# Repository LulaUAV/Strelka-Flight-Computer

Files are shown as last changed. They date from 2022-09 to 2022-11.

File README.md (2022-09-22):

# Strelka-Flight-Computer
Strelka exists in the family of rocket dog flight computers. This flight computer is fully capable of deploying recovery events.

Strelka (Стрелка, "little arrow") was a dog that spent a day in space aboard Korabl-Sputnik 2 (Sputnik 5) on 19 August 1960 before safely returning to Earth.

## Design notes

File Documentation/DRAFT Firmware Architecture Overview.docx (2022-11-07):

# Firmware Architecture Overview

# Header Files:

actuator_control.h:

data_logging.h:

Ematch_actuators.h:

max_m10.h:

ms5611.h:

bmx055.h:

# Data handling:

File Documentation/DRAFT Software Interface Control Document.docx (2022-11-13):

# Software Interface Control Document

# Preface:

This document outlines the internal software interfaces within the Strelka PCB environment. These interfaces are separated into two sections being the communication between the host processor and power distribution processor and the communication between the host processor and the ground station over a 915MHz RF link.

# Actuator control interface:

This interface consists of a SPI communications bus between the host board and the power distribution board. Communications will be initiated by the master when the chip select (CS) pin is pulled low. The master either send commands or request data. Due to hardware limitations, SPI packets must be of a fixed length. The communication bus packets will consist of the following fields:

Packet field | Identifier | Payload | Padding | CRC32
Data type | uint8_t | uint8_t | uint8_t | uint32_t
Length (bytes) | 1 | variable | Variable | 4
Description | Signify the packet type | Fields containing fixed length payloads | Padding to ensure packet size is equal to PACKET_SIZE | 32-bit CRC checksum

## Packet types:

Set servo positions:

Sets the positions of the 4 servos.

Sent from master:

Length: 21 bytes

Set servo positions | Identifier | Servo 1 position | Servo 2 position | Servo 3 position | Servo 4 position | Padding | CRC32
Data type | uint8_t | uint32_t | uint32_t | uint32_t | uint32_t | uint8_t | uint32_t
Length (bytes) | 1 | 4 | 4 | 4 | 4 | 0 | 4
Value | 0x44 | - | - | - | - | 0 | -

Received from slave:

Set servo positions response | Identifier | Actuator control state TypeDef | CRC32
Data type | uint8_t | uint32_t | uint32_t
Length (bytes) | 1 | 1 | 4
Value | 0x44 | - | -

Set DC motor positions:

Sets the angular positions of the two DC motors.

Set DC motor positions | Identifier | Motor 1 position | Motor 2 position | CRC32
Data type | uint8_t | uint32_t | uint32_t | uint32_t
Length (bytes) | 1 | 4 | 4 | 4
Value | 0x45 | - | - | -

Set DC motor rate:

Sets the angular rate of the two DC motors.

Set DC motor rate | Identifier | Motor 1 position | Motor 2 position | CRC32
Data type | uint8_t | uint32_t | uint32_t | uint32_t
Length (bytes) | 1 | 4 | 4 | 4
Value | 0x46 | - | - | -

Set DC motor gains:

Sets the control gains used to control the DC motors.

Set DC motor gains | Identifier | Motor 1 Kp | Motor 1 Ki | Motor 1 Kd | Motor 2 Kp | Motor 2 Ki | Motor 2 Kd | CRC32
Data type | uint8_t | uint16_t | uint16_t | uint16_t | uint16_t | uint16_t | uint16_t | uint32_t
Length (bytes) | 1 | 2 | 2 | 2 | 2 | 2 | 2 | 4
Value | 0x47 | - | - | - | - | - | - | -

Request DC motor positions:

Sent from master:

Request stepper motor rate | Identifier | CRC32
Data type | uint8_t | uint32_t
Length (bytes) | 1 | 4
Value | 0x48 | -

Received from slave:

Request DC motor positions | Identifier | Motor 1 position | Motor 2 position | CRC32
Data type | uint8_t | uint32_t | uint32_t | uint32_t
Length (bytes) | 1 | 4 | 4 | 4
Value | 0x49 | - | - | -

Request DC motor rates:

Sent from master:

Request stepper motor rate | Identifier | CRC32
Data type | uint8_t | uint32_t
Length (bytes) | 1 | 4
Value | 0x4A | -

Received from slave:

Request DC motor positions | Identifier | Motor 1 rate | Motor 2 rate | CRC32
Data type | uint8_t | uint32_t | uint32_t | uint32_t
Length (bytes) | 1 | 4 | 4 | 4
Value | 0x4B | - | - | -

Set stepper motor position:

Sets the position of the single stepper motor.

Set stepper motor position | Identifier | Motor 1 position | CRC32
Data type | uint8_t | uint32_t | uint32_t
Length (bytes) | 1 | 4 | 4
Value | 0x4C | - | -

Set stepper motor rate:

Sets the angular rate of the stepper motor.

Set stepper motor rate | Identifier | Motor 1 position | CRC32
Data type | uint8_t | uint32_t | uint32_t
Length (bytes) | 1 | 4 | 4
Value | 0x4D | - | -

Request stepper motor rate:

Requests the angular rate of the stepper motor.

Sent from master:

Request stepper motor rate | Identifier | CRC32
Data type | uint8_t | uint32_t
Length (bytes) | 1 | 4
Value | 0x4E | -

Received from slave:

Set stepper motor rate | Identifier | Motor 1 position | CRC32
Data type | uint8_t | uint32_t | uint32_t
Length (bytes) | 1 | 4 | 4
Value | 0x4E | - | -

# Ground station control interface:

This interface consists of a RF link between the Strelka PCB (slave) and the ground station (master). The radio communication is at 915MHz using LoRa modulation. Communications are half duplex and always initiated by the ground station. Data will be transmitted back from the Strelka PCB only after a request is made by the ground station.

## Packet types:

Test gimbal:

Sent from master:

Test gimbal | Identifier | CRC32
Data type | uint8_t | uint32_t
Length (bytes) | 1 | 4
Value | 0x01 | -

Received from slave:

Test gimbal | Identifier | Result | CRC32
Data type | uint8_t | uint8_t | uint32_t
Length (bytes) | 1 | 1 | 4
Value | 0x01 | 0 or 1 | -

Get continuity:

Sent from master:

Get continuity | Identifier | CRC32
Data type | uint8_t | uint32_t
Length (bytes) | 1 | 4
Value | 0x02 | -

Received from slave:

Get continuity | Identifier | Main continuity | Drogue continuity | CRC32
Data type | uint8_t | uint8_t | uint8_t | uint32_t
Length (bytes) | 1 | 1 | 1 | 4
Value | 0x01 | 0 or 1 | 0 or 1 | -

Get battery voltage:

Sent from master:

Get battery voltage | Identifier | CRC32
Data type | uint8_t | uint32_t
Length (bytes) | 1 | 4
Value | 0x01 | -

Received from slave:

Get battery voltage | Identifier | Battery voltage | CRC32
Data type | uint8_t | uint32_t | uint32_t
Length (bytes) | 1 | 4 | 4
Value | 0x01 | 0 or 1 | -

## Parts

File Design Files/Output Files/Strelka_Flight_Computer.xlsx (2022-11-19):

Source: | C:\Users\thean\Documents\FYP\Strelka-Flight-Computer\Design Files\Strelka_Flight_Computer\Strelka_Flight_Computer.kicad_sch
Date: | 2022-11-12 10:20
Tool: | Eeschema (6.0.9)
Generator: | C:\Program Files\KiCad\6.0\bin\scripting\plugins/bom_csv_grouped_by_value.py
Component Count: | 166
Item | Qty | Reference(s) | Value | LibPart | Footprint | Datasheet | LCSC# | Link | Qty | Price (USD) | Price (AUD) | Total | Exchange rate (USB->AUD)
1 | 1 | AE1 | Antenna_Shield | Device:Antenna_Shield | Connector_Coaxial:SMA_Amphenol_132134_Vertical | ~ | C2874833 |  |  |  |  | $0.00 | 1.49
2 | 1 | AE2 | Antenna_Shield | Device:Antenna_Shield | Connector_Coaxial:U.FL_Hirose_U.FL-R-SMT-1_Vertical | ~ | C88373 |  | 10 | $0.16 | $0.23 | $2.31
3 | 1 | BT2 | MS621FE-FL11E | MS621FE-FL11E:MS621FE-FL11E | Footprints:BAT_MS621FE-FL11E | http://www.sii.co.jp/en/me/datasheets/ms-rechargeable/ms621fe/ |  | https://www.ebay.com.au/itm/263174584953 | 1 | $6.47 | $9.64 | $9.64
4 | 4 | C1, C4, 14, 16, C26, C27 | 2.2u | Device:C_Small | Capacitor_SMD:C_0603_1608Metric | ~ | C92760 |  |  |  | $0.00 | $0.00
5 | 2 | C2, C23, C47 | 1u | Device:C_Small | Capacitor_SMD:C_0603_1608Metric | ~ | C5673 |  |  |  | $0.00 | $0.00
6 | 1 | C3, C17, C18 | 10nF | Device:C_Small | Capacitor_SMD:C_0603_1608Metric | ~ | C342901 |  |  |  | $0.00 | $0.00
8 | 3 | C6, C7, C10, C12, C13, C28, C29, C30, C31, C36, C39, C48 | 100nF | Device:C_Small | Capacitor_SMD:C_0603_1608Metric_Pad1.08x0.95mm_HandSolder | ~ | C30926 |  |  |  | $0.00 | $0.00
9 | 4 | C8, C9, C11, C15, C40 | 10uF | Device:C_Small | Capacitor_SMD:C_0603_1608Metric_Pad1.08x0.95mm_HandSolder | ~ | C87152 |  |  |  | $0.00 | $0.00
13 | 2 | C19, C20 | 8pF | Device:C_Small | Capacitor_SMD:C_0603_1608Metric_Pad1.08x0.95mm_HandSolder | ~ | C575408 |  |  |  | $0.00 | $0.00
14 | 2 | C21, C22 | 18pF | Device:C_Small | Capacitor_SMD:C_0603_1608Metric_Pad1.08x0.95mm_HandSolder | ~ | C519452 |  |  |  | $0.00 | $0.00
18 | 1 | C37 | NC | Device:C_Small | Capacitor_SMD:C_0402_1005Metric | ~ |  |  |  |  | $0.00 | $0.00
19 | 1 | C38 | 4.7u | Device:C_Small | Capacitor_SMD:C_0603_1608Metric | ~ | C92758 |  | 50 | $0.01 | $0.02 | $1.11
21 | 1 | C41 | 1500u | Device:C_Polarized_Small | Capacitor_THT:C_Radial_D8.0mm_H11.5mm_P3.50mm | ~ | C248440 |  | 5 | $0.25 | $0.38 | $1.88
22 | 1 | C46 | 22u | Device:C_Small | Capacitor_SMD:C_0603_1608Metric | ~ | C2762594 |  | 5 | $0.08 | $0.12 | $0.62
24 | 7 | C49, C50, C52, C53, C54, C56, C57 | NC | Device:C_Small | Capacitor_SMD:C_0603_1608Metric | ~ |  |  |  |  | $0.00 | $0.00
25 | 1 | C51 | 820p | Device:C_Small | Capacitor_SMD:C_0603_1608Metric | ~ | C5186722 |  | 100 | $0.0028 | $0.004172 | $0.42
26 | 1 | C55 | 47uF | Device:C_Small | Capacitor_SMD:C_0805_2012Metric | ~ | C76636 |  | 5 | $0.27 | $0.41 | $2.04
27 | 3 | D1, D2, D4 | B5819W | Device:D_Schottky_Small | Diode_SMD:D_SOD-123 | ~ | C8598 |  | 20 | $0.03 | $0.05 | $0.95
28 | 1 | D3 | E6X0602QBAC1UDA | Device:LED | LED_SMD:LED_0603_1608Metric_Pad1.05x0.95mm_HandSolder | https://datasheet.lcsc.com/lcsc/2105241210_EKINGLUX-E6X0602QBAC1UDA_C375467.pdf | C375467 |  |  |  | $0.00 | $0.00
29 | 2 | D5, D9 | 1SS388 | Device:D_Schottky_Small_Filled | Diode_SMD:D_SOD-523 | https://datasheet.lcsc.com/lcsc/2204061830_TECH-PUBLIC-1SS388_C2987059.pdf | C2987059 |  | 20 | $0.03 | $0.04 | $0.89
30 | 1 | D6 | SP0504BAJT | Power_Protection:SP0504BAJT | Package_TO_SOT_SMD:SOT-353_SC-70-5 | http://www.littelfuse.com/~/media/files/littelfuse/technical%20resources/documents/data%20sheets/sp05xxba.pdf | C5116451 |  | 5 | $0.08 | $0.12 | $0.59
31 | 1 | D10 | ESD9B3.3ST5G | Diode:ESD9B3.3ST5G | Diode_SMD:D_0402_1005Metric | https://datasheet.lcsc.com/lcsc/2108131930_TECH-PUBLIC-TPESD0402G36V_C558621.pdf | C558621 |  | 40 | $0.03 | $0.05 | $1.90
32 | 1 | D11 | BAT54C | Diode:BAT54C | Package_TO_SOT_SMD:SOT-23 | http://www.diodes.com/_files/datasheets/ds11005.pdf | C37704 |  | 20 | $0.02 | $0.04 | $0.74
33 | 1 | D12 | RED_BLUE | Device:LED_Small | LED_SMD:LED_0603_1608Metric | ~ | C84263 |  | 50 | $0.01 | $0.01 | $0.63
34 | 1 | D13 | BZT52C3V6T | Device:D_Zener_Small_Filled | Diode_SMD:D_SOD-523 | https://datasheet.lcsc.com/lcsc/2108150230_MDD-Microdiode-Electronics--BZT52C3V6T_C2858499.pdf | C2858499 |  | 50 | $0.02 | $0.03 | $1.34
35 | 1 | D14 | DSK34 | Device:D_Schottky_Small_Filled | Diode_SMD:D_SOD-123 | https://datasheet.lcsc.com/lcsc/1912171423_High-Diode-SS34_C466502.pdf | C908230 |  | 20 | $0.03 | $0.05 | $0.95
36 | 2 | FB1, FB2 | BLM18PG221SN1D | Device:FerriteBead_Small | Inductor_SMD:L_0603_1608Metric | https://datasheet.lcsc.com/lcsc/1810311127_Murata-Electronics-BLM18PG221SN1D_C80165.pdf | C80165 |  | 50 | $0.01 | $0.02 | $0.89
37 | 1 | FB3 | HZ1005K182TFB03 | Device:FerriteBead_Small | Resistor_SMD:R_0402_1005Metric | ~ | C279553 |  | 50 | $0.01 | $0.02 | $0.85
39 | 2 | I1, I2 | AL5809-30S1-7 | Simulation_SPICE:IDC | Diode_SMD:D_SOD-123 | https://datasheet.lcsc.com/lcsc/1809290411_Diodes-Incorporated-AL5809-30S1-7_C151325.pdf | C151325 |  | 4 | $0.37 | $0.54 | $2.18
40 | 1 | IC1 | XTSD04GLGEAG | XTSD04GLGEAG:XTSD04GLGEAG | SON127P800X600X95-8N | https://datasheet.lcsc.com/szlcsc/2005251034_XTX-XTSD04GLGEAG_C558839.pdf | C558839 |  | 2 | $0.51 | $0.76 | $1.52
41 | 1 | IC2 | MAX-M10S-00B | MAX-M10S-00B:MAX-M10S-00B | Footprints:MAXM10S00B | https://content.u-blox.com/sites/default/files/MAX-M10S_IntegrationManual_UBX-20053088.pdf |  | https://www.digikey.com.au/en/products/detail/u-blox/MAX-M10S-00B/15712906 | 1 |  | $34.07 | $34.07
42 | 1 | J1 | 1S_LiPo_LARGE_HOLE_XT-30 | Connector:Conn_01x02_Female | Connector_AMASS:AMASS_XT30PW-M_1x02_P2.50mm_Horizontal | https://www.ebay.com.au/itm/274528359927 |  |  | 1 |  | $14.00 | $14.00
43 | 1 | J2 | SM04B-GHS-TB(LF)(SN)- | SM04B-GHS-TB_LF__SN_-:SM04B-GHS-TB(LF)(SN)- | Footprints:JST_SM04B-GHS-TB(LF)(SN)- | https://datasheet.lcsc.com/lcsc/1810261120_JST-Sales-America-SM04B-GHS-TB-LF-SN_C189895.pdf | C189895 |  | 10 | $0.13 | $0.19 | $1.91
44 | 1 | J3 | DB125-3.5-4P-GN-S | Connector:Screw_Terminal_01x04 | TerminalBlock_4Ucon:TerminalBlock_4Ucon_1x04_P3.50mm_Horizontal | https://datasheet.lcsc.com/lcsc/2106062245_DIBO-DB125-3-5-4P-GN-S_C2757925.pdf | C2757925 |  | 5 | $0.27 | $0.40 | $2.00
45 | 1 | J4 | SM06B-GHS-TB(LF)(SN) | SM06B-GHS-TB_LF__SN_:SM06B-GHS-TB(LF)(SN) | Footprints:JST_SM06B-GHS-TB(LF)(SN) |  | C133065 |  | 10 | $0.29 | $0.43 | $4.31
46 | 1 | J5 | USB_B_Micro | Connector:USB_B_Micro | Connector_USB:USB_Micro-B_Molex-105017-0001 | ~ |  |  |  |  | $0.00 | $0.00
47 | 1 | J6 | USB_B_Micro | :USB_B_Micro_1 | Connector_USB:USB_Micro-B_Molex-105017-0001 | ~ |  |  |  |  | $0.00 | $0.00
49 | 1 | L2 | 6u | Device:L_Small | Inductor_SMD:L_Bourns_SRP5030T | https://datasheet.lcsc.com/lcsc/2105092345_BOURNS-SRP5030T-6R8M_C1329837.pdf | C1329837 |  | 2 | $0.99 | $1.47 | $2.94
50 | 1 | MOSFET1 | DMG6968UDM-7 | DMG6968UDM-7:DMG6968UDM-7 | Footprints:DMG6968UDM-7 | https://www.diodes.com/assets/Datasheets/ds31758.pdf | C151635 |  | 2 | $0.21 | $0.31 | $0.63
51 | 2 | Q1, Q2 | CJK2333 | Transistor_FET:Si2319CDS | Package_TO_SOT_SMD:SOT-23 | https://datasheet.lcsc.com/lcsc/2010190933_Jiangsu-Changjing-Electronics-Technology-Co---Ltd--CJK2333_C504109.pdf | C504109 |  | 5 | $0.07 | $0.11 | $0.56
52 | 4 | Q3, Q4, Q8, Q9 | AO3401A | Transistor_FET:AO3401A | Package_TO_SOT_SMD:SOT-23 | http://www.aosmd.com/pdfs/datasheet/AO3401A.pdf | C347476 |  | 20 | $0.03 | $0.05 | $0.93
53 | 2 | Q5, Q10 | AP2300 | Transistor_FET:2N7002E | Package_TO_SOT_SMD:SOT-23 | https://datasheet.lcsc.com/lcsc/1912111437_ALLPOWER-ShenZhen-Quan-Li-Semiconductor-AP2300_C360338.pdf | C360338 |  |  |  | $0.00 | $0.00
54 | 2 | Q6, Q11 | MMBT2222 | Device:Q_NPN_BCE | Package_TO_SOT_SMD:SOT-23 | chrome-extension://efaidnbmnnnibpcajpcglclefindmkaj/https://www.onsemi.com/pdf/datasheet/mmbt2222lt1-d.pdf | C8512 |  |  |  | $0.00 | $0.00
55 | 10 | R3, R8, R29, R30, R32, R49, R50, R52, R64, R69 | 100k | Device:R_Small | Resistor_SMD:R_0603_1608Metric | ~ | C14675 |  | 100 | $0.0011 | $0.001639 | $0.16
56 | 1 | R7 | 330R | Device:R_Small | Resistor_SMD:R_0603_1608Metric | ~ | C105881 |  | 100 | $0.0013 | $0.001937 | $0.19
57 | 1 | R9 | 2.7k | Device:R_Small | Resistor_SMD:R_0603_1608Metric | ~ | C13167 |  | 100 | $0.0009 | $0.001341 | $0.13
58 | 2 | R10, R23 | 10k | Device:R_Small | Resistor_SMD:R_0603_1608Metric | ~ | C98220 |  |  |  | $0.00 | $0.00
59 | 2 | R11, R12, R21, R22, R25 | 10R | Device:R_Small | Resistor_SMD:R_0603_1608Metric | ~ | C109318 |  |  |  | $0.00 | $0.00
60 | 1 | R13 | 200R | Device:R_Small | Resistor_SMD:R_0603_1608Metric_Pad0.98x0.95mm_HandSolder | ~ | C114664 |  |  |  | $0.00 | $0.00
61 | 6 | R14, R15, R16, R17, R18, R19, R20, R40, R58, R55 | 0 | Device:R_Small | Resistor_SMD:R_0603_1608Metric_Pad0.98x0.95mm_HandSolder | ~ | C21189 |  | 100 | $0.001 | $0.00149 | $0.15
62 | 1 | R55 | 0 | Device:R_Small | Resistor_SMD:R_0402_1005Metric |  | C106231 |  | 100 | $0.0006 | $0.000894 | $0.09
64 | 1 | R24 | NC | Device:R_Small | Resistor_SMD:R_0603_1608Metric_Pad0.98x0.95mm_HandSolder | ~ |  |  |  |  | $0.00 | $0.00
65 | 2 | R27, R47 | 2R | Device:R_Small | Resistor_SMD:R_2512_6332Metric | https://lcsc.com/product-detail/Chip-span-style-background-color-ff0-Resistor-span-Surface-Mount_UNI-ROYAL-Uniroyal-Elec-HP122WF200KT4E_C91926.html | C91926 |  | 8 | $0.20 | $0.30 | $2.37
66 | 10 | R28, R31, R33, R34, R48, R51, R53, R54, R56, R57 | 1k | Device:R_Small | Resistor_SMD:R_0603_1608Metric | ~ | C22548 |  | 100 | $0.0011 | $0.001639 | $0.16
67 | 6 | R35, R36, R37, R38, R39, R60 | 47k | Device:R_Small | Resistor_SMD:R_0603_1608Metric | ~ | C105579 |  | 200 | $0.0013 | $0.001937 | $0.39
70 | 1 | R59 | 13k | Device:R_Small | Resistor_SMD:R_0603_1608Metric | ~ | C137796 |  | 100 | $0.0014 | $0.002086 | $0.21
71 | 1 | R61 | 56.2k | Device:R_Small | Resistor_SMD:R_0603_1608Metric | ~ | C2930117 |  | 100 | $0.0009 | $0.001341 | $0.13
72 | 1 | R62 | 82k | Device:R_Small | Resistor_SMD:R_0603_1608Metric | ~ | C23254 |  | 100 | $0.001 | $0.00149 | $0.15
73 | 1 | R63 | 27k | Device:R_Small | Resistor_SMD:R_0603_1608Metric | ~ | C22967 |  | 100 | $0.0009 | $0.001341 | $0.13
74 | 4 | R65, R66, R67, R68 | 33 | Device:R_Small | Resistor_SMD:R_0603_1608Metric_Pad0.98x0.95mm_HandSolder | ~ | C23140 |  | 100 | $0.0001 | $0.000149 | $0.01
75 | 2 | SW1, SW2 | SW_Push | Nebula-rescue:SW_Push-Switch-H7_FlightComputer-rescue | Button_Switch_SMD:SW_Push_SPST_NO_Alps_SKRK |  | C561518 |  | 20 | $0.05 | $0.08 | $1.60
76 | 1 | SW3 | SM02B-GHS-TB(LF)(SN) | Switch:SW_DIP_x01 | Footprints:SM02BGHSTBLFSN | https://datasheet.lcsc.com/lcsc/1810261111_JST-Sales-America-SM02B-GHS-TB-LF-SN_C189893.pdf | C189893 |  | 10 | $0.11 | $0.16 | $1.65
77 | 1 | U2 | AP9101CK6 | Battery_Management:AP9101CK6 | Package_TO_SOT_SMD:SOT-23-6 | https://www.diodes.com/assets/Datasheets/AP9101C.pdf | C151339 |  |  |  | $0.00 | $0.00
78 | 1 | U3 | AMS1117-3.3 | Regulator_Linear:AMS1117-3.3 | Package_TO_SOT_SMD:SOT-223-3_TabPin2 | http://www.advanced-monolithic.com/pdf/ds1117.pdf | C173386 |  |  |  | $0.00 | $0.00
79 | 1 | U4 | RFM95W-915S2 | RF_Module:RFM95W-915S2 | RF_Module:HOPERF_RFM9XW_SMD | https://www.hoperf.com/data/upload/portal/20181127/5bfcbea20e9ef.pdf | C2844473 |  |  |  | $0.00 | $0.00
80 | 1 | U5 | STM32F405RGTx | MCU_ST_STM32F4:STM32F405RGTx | Package_QFP:LQFP-64_10x10mm_P0.5mm | http://www.st.com/st-web-ui/static/active/en/resource/technical/document/datasheet/DM00037051.pdf | C15742 |  | 2 | $13.79 | $20.55 | $41.10
81 | 2 | U7, U8 | USBLC6-2SC6 | Power_Protection:USBLC6-2SC6 | Package_TO_SOT_SMD:SOT-23-6 | https://www.st.com/resource/en/datasheet/usblc6-2.pdf | C2687116 |  |  |  | $0.00 | $0.00
82 | 1 | U9 | CP2102N-Axx-xQFN28 | Interface_USB:CP2102N-Axx-xQFN28 | Package_DFN_QFN:QFN-28-1EP_5x5mm_P0.5mm_EP3.35x3.35mm | https://www.silabs.com/documents/public/data-sheets/cp2102n-datasheet.pdf | C1550553 |  | 1 | $1.12 | $1.67 | $1.67
83 | 2 | U10, U15 | LM321 | Amplifier_Operational:LM321 | Package_TO_SOT_SMD:SOT-23-5 | http://www.ti.com/lit/ds/symlink/lm321.pdf | C5189111 |  | 10 | $0.04 | $0.06 | $0.65
84 | 1 | U11 | BMX055 | BMX055:BMX055 | Footprints:BMX055 | https://datasheet.lcsc.com/lcsc/1811071031_Bosch-Sensortec-BMX055_C94022.pdf | C94022 |  | 2 | $15.82 | $23.57 | $47.14
85 | 1 | U12 | MS561101BA03-50 | MS561101BA03-50:MS561101BA03-50 | Footprints:MS561101BA03-50 | https://www.te.com/commerce/DocumentDelivery/DDEController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 |  |  | 1 |  | $20.93 | $20.93
86 | 1 | U16 | TPS61085DGKR | TPS61085DGKR:TPS61085DGKR | Footprints:SOP65P490X110-8N | https://www.ti.com/cn/lit/gpn/tps61085 | C113659 |  | 2 | $1.52 | $2.26 | $4.52
87 | 1 | Y1 | Q13FC1350000200 | Device:Crystal_Small | Crystal:Crystal_SMD_3215-2Pin_3.2x1.5mm | https://datasheet.lcsc.com/lcsc/1811081213_Seiko-Epson-Q13FC1350000200_C48615.pdf | C48615 |  |  |  | $0.00 | $0.00
88 | 1 | Y2 | X322524MOB4SI | Device:Crystal_GND24_Small | Crystal:Crystal_SMD_3225-4Pin_3.2x2.5mm | https://datasheet.lcsc.com/lcsc/2103291204_Yangxing-Tech-X322524MOB4SI_C70590.pdf | C70590 |  |  |  | $0.00 | $0.00
 |  |  |  |  |  |  |  |  |  | Total (AUD) |  | $216.36
 |  |  |  |  |  |  |  |  |  | Already purchased
 |  |  |  |  |  |  |  |  |  | Purchased

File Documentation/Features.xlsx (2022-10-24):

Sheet: Features
Feature | Notes | Product
USB
Boost converter | 1s lipo | FP6276BXR-G1 (https://www.lcsc.com/product-detail/DC-DC-Converters_Feeling-Tech-FP6276BXR-G1_C82652.html)
LVCO
Servo outputs
Radio | RFM95W
GPS
Continuity testing
Brownout protection
Buzzer
Status LEDs

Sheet: Continuity Testing
Parts required | Part number | Specs
Constant current source | LM334Z/NOPB | 1uA-10mA output, High side config
Op amp | LM324

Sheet: MCU Selection
MCU | CPU (MHz) | Flash (kB) | RAM (kB) | Extras | Price (USD)
STM32F402RCT6 (https://lcsc.com/product-detail/Microcontroller-Units-MCUs-MPUs-SOCs_STMicroelectronics-STM32F402RCT6_C2915304.html) | 84 | 256 | 64 | FPU | 5.4587
STM32F405RGT6 (https://lcsc.com/product-detail/ST-Microelectronics_STMicroelectronics-STM32F405RGT6_C15742.html) | 168 | 1000 | 192 | FPU | 15 | These are hot swappable if vcap_1 and vcap_2 for f405 can have capacitor replaced with 0 ohm resistor when F446
STM32F446RET6 (https://lcsc.com/product-detail/ST-Microelectronics_STMicroelectronics-STM32F446RET6_C69336.html) | 180 | 512 | 128 | FPU | 14.154
STM32WB55CGU6 (https://lcsc.com/product-detail/Microcontroller-Units-MCUs-MPUs-SOCs_STMicroelectronics-STM32WB55CGU6_C404023.html) | 64 | 1999 | 256 | BT | 10.61

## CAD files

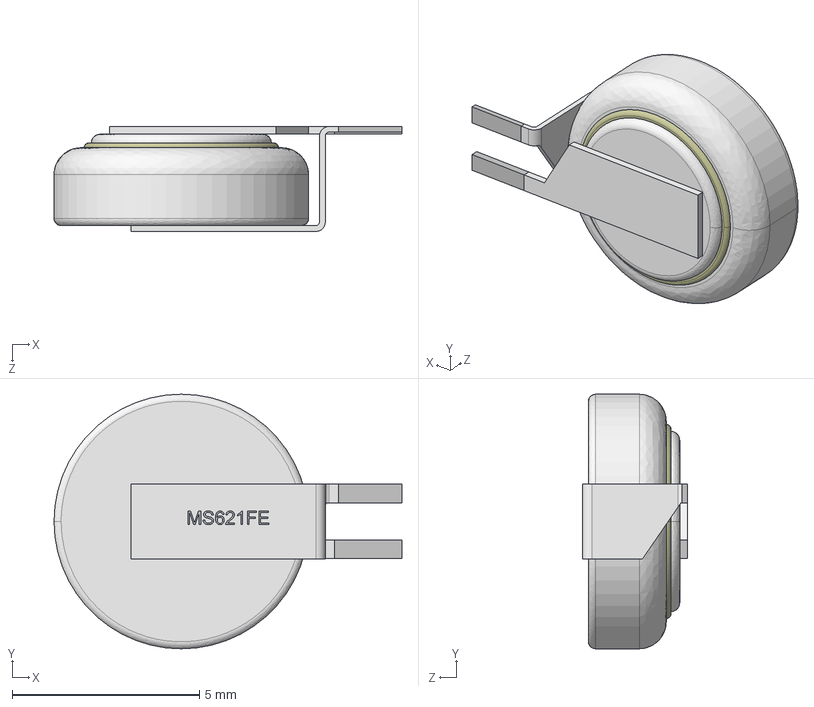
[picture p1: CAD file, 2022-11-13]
Local Library/3D Models/MS621FE-1.STEP
9.29 x 6.80 x 2.80 mm

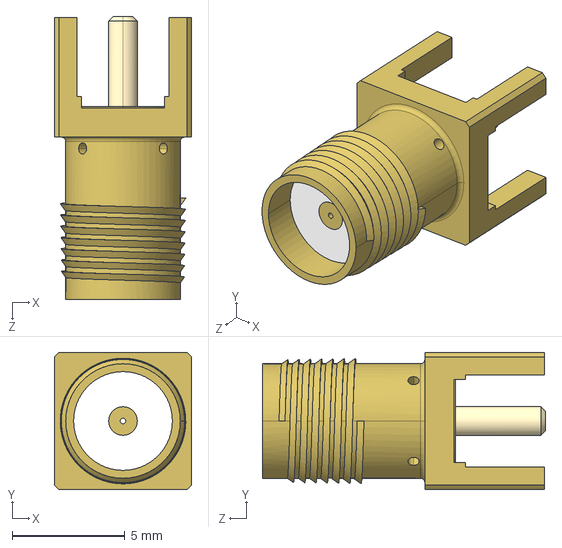
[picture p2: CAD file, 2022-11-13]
Local Library/3D Models/Molex - 73391-0060.STEP
6.08 x 6.08 x 12.6 mm

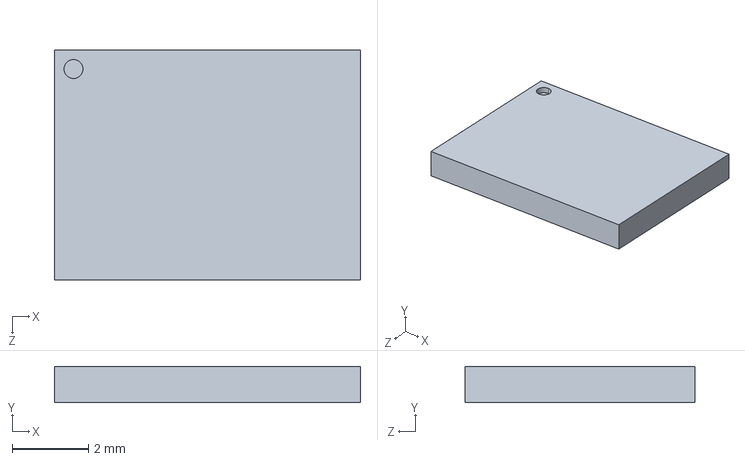
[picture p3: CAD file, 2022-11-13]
Local Library/3D Models/XTSD04GLGEAG.STEP
8.05 x 0.95 x 6.05 mm

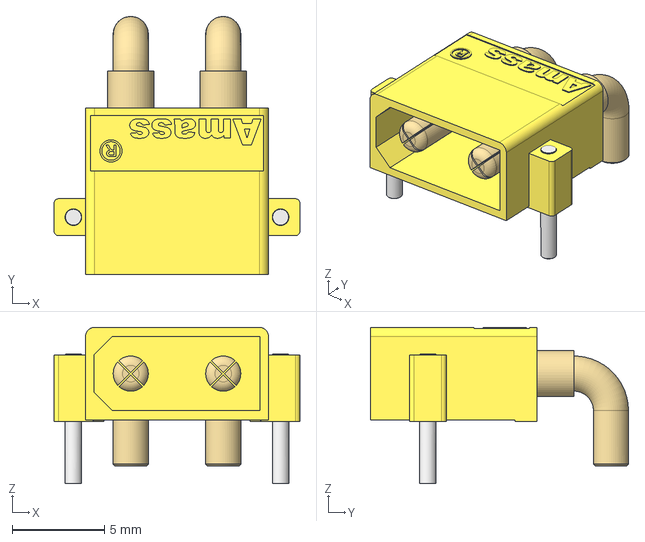
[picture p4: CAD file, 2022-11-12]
Local Library/3D Models/Amass_XT30PW-M.stp
13.3 x 13.9 x 8.45 mm

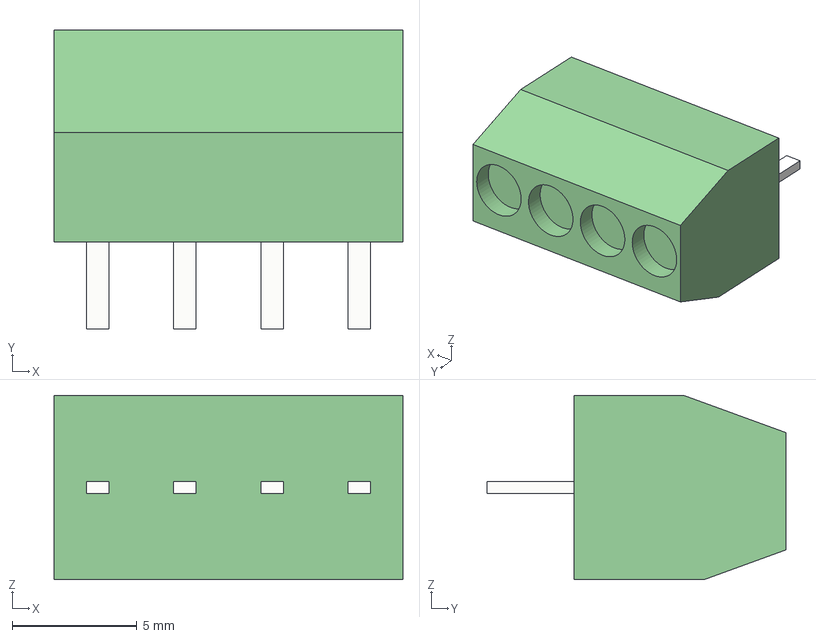
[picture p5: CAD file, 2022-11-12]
Local Library/3D Models/DB125-3.5-4P-GN-S.step
14.0 x 12.0 x 7.40 mm

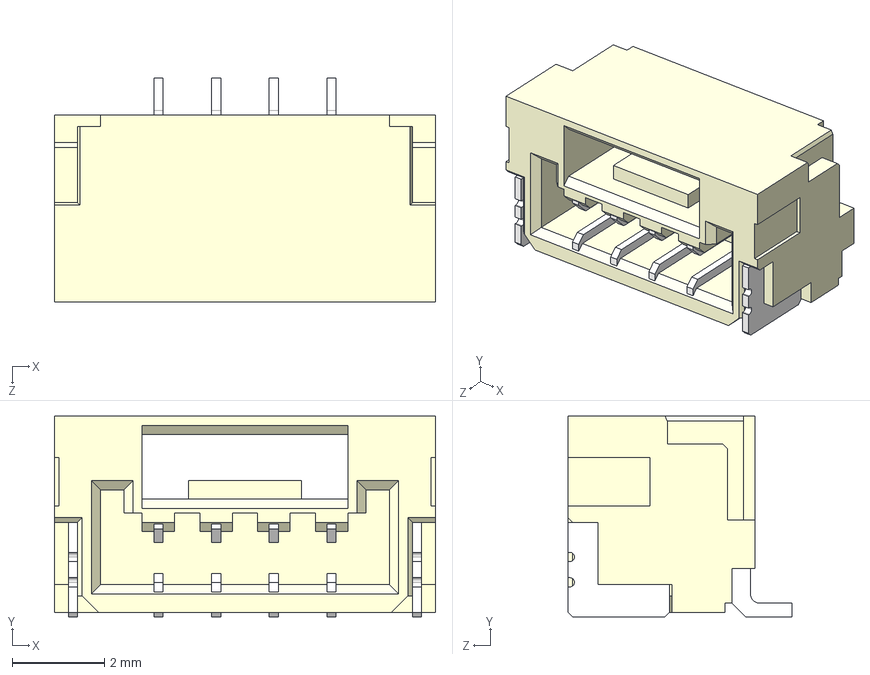
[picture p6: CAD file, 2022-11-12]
Local Library/3D Models/SM04B-GHS-TB_LF__SN_-.step
8.25 x 4.35 x 4.85 mm

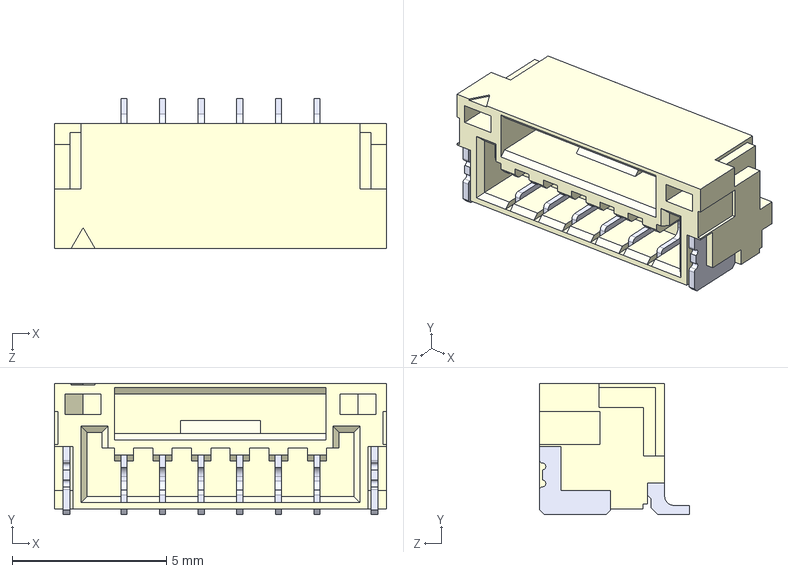
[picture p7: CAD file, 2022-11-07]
Local Library/3D Models/SM06B-GHS-TB_LF__SN_.step
10.8 x 4.25 x 4.85 mm

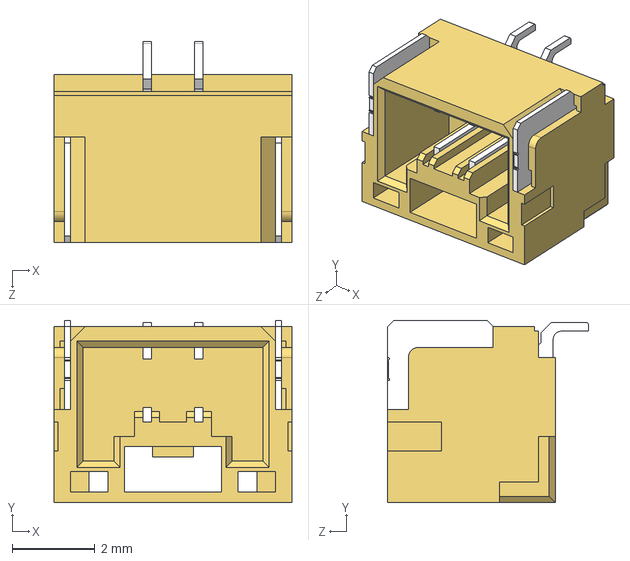
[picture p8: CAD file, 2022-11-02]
Local Library/3D Models/SM02B-GHS-TB_LF__SN_.stp
5.75 x 4.40 x 4.85 mm

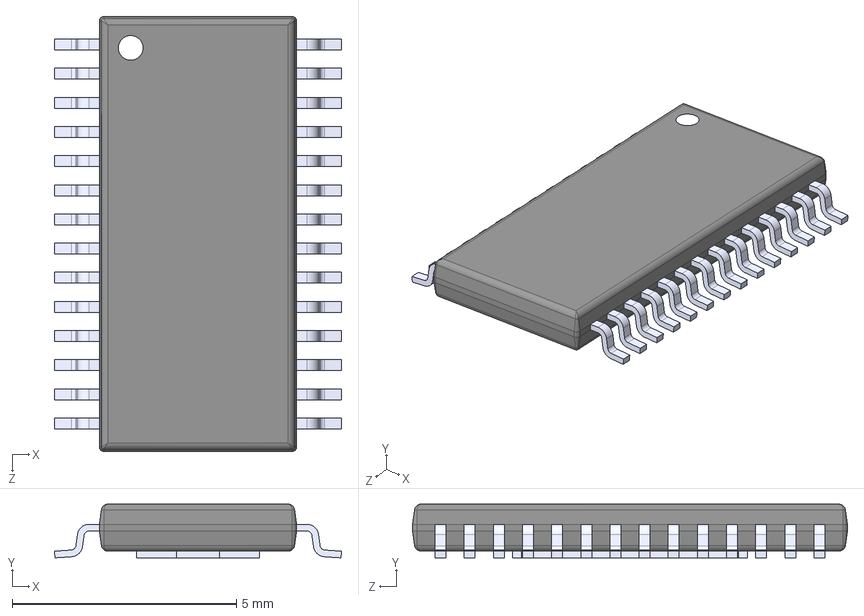
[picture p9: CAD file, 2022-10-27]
Local Library/3D Models/DRV8825PWPR.step
6.40 x 1.20 x 9.70 mm

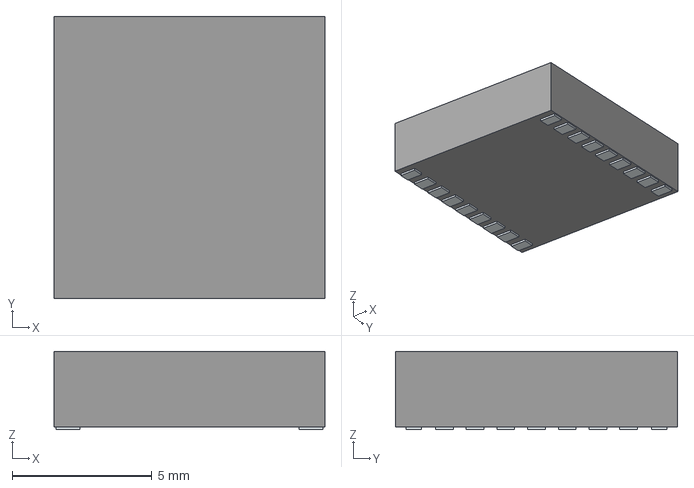
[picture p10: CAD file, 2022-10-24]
Local Library/3D Models/MAX-M10S-00B.stp
9.70 x 10.1 x 2.80 mm
Pins

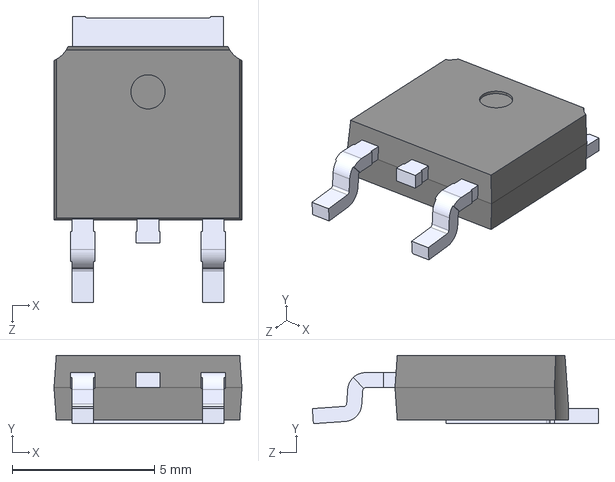
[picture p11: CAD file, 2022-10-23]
Local Library/3D Models/SBRD10200TR.step
6.60 x 2.40 x 10.1 mm

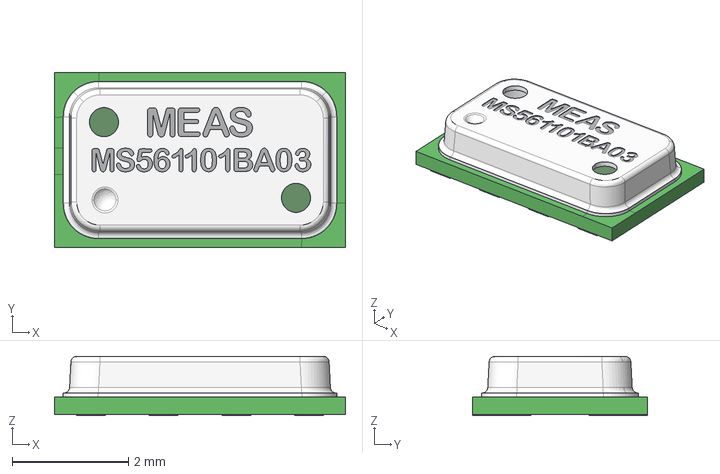
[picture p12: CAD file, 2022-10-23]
Local Library/3D Models/MS5611-01BA03.stp
5.00 x 3.00 x 1.02 mm

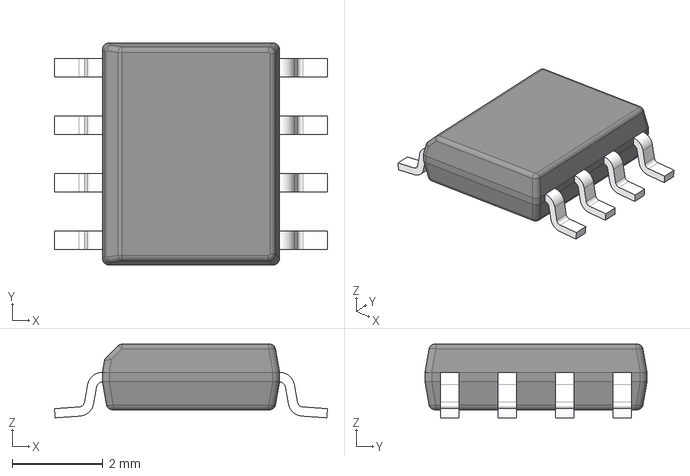
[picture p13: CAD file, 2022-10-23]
Local Library/3D Models/TPS54331D.stp
6.02 x 4.90 x 1.63 mm
BODY-SO
LEAD-D0008A x 8

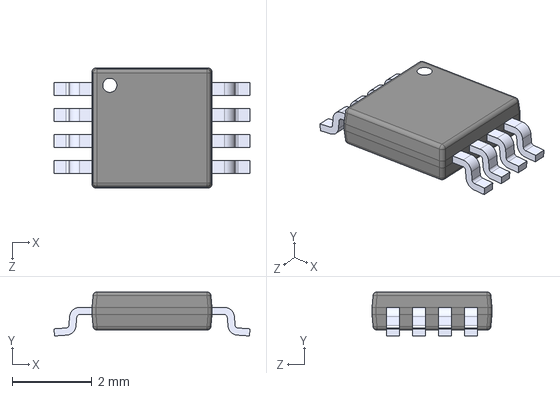
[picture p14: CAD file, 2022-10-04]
Local Library/3D Models/TPS61085DGKR.step
4.90 x 1.10 x 3.00 mm

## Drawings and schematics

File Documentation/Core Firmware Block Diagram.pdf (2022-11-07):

# Core Firmware Block Diagram

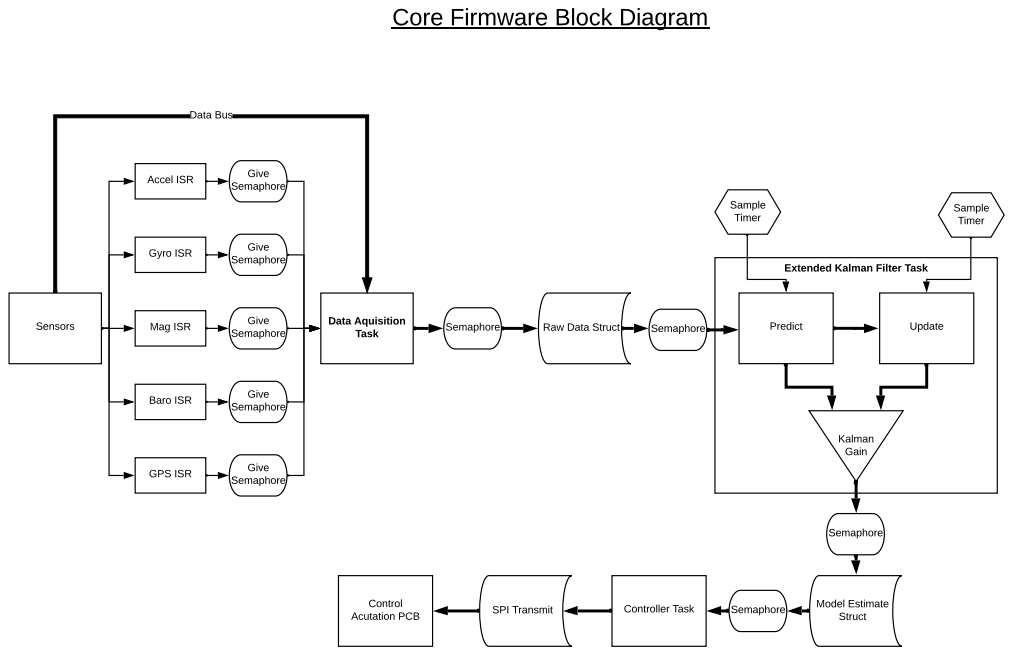
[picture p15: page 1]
Accel ISR; Gyro ISR; Mag ISR; Baro ISR; GPS ISR; Sensors; Data Aquisition; Task; Give Semaphore; Semaphore; Raw Data Struct; Data Bus; Predict; Update; Kalman Gain; Controller Task; Sample Timer; Model Estimate Struct

Extended Kalman Filter Task

SPI Transmit Control
Acutation PCB

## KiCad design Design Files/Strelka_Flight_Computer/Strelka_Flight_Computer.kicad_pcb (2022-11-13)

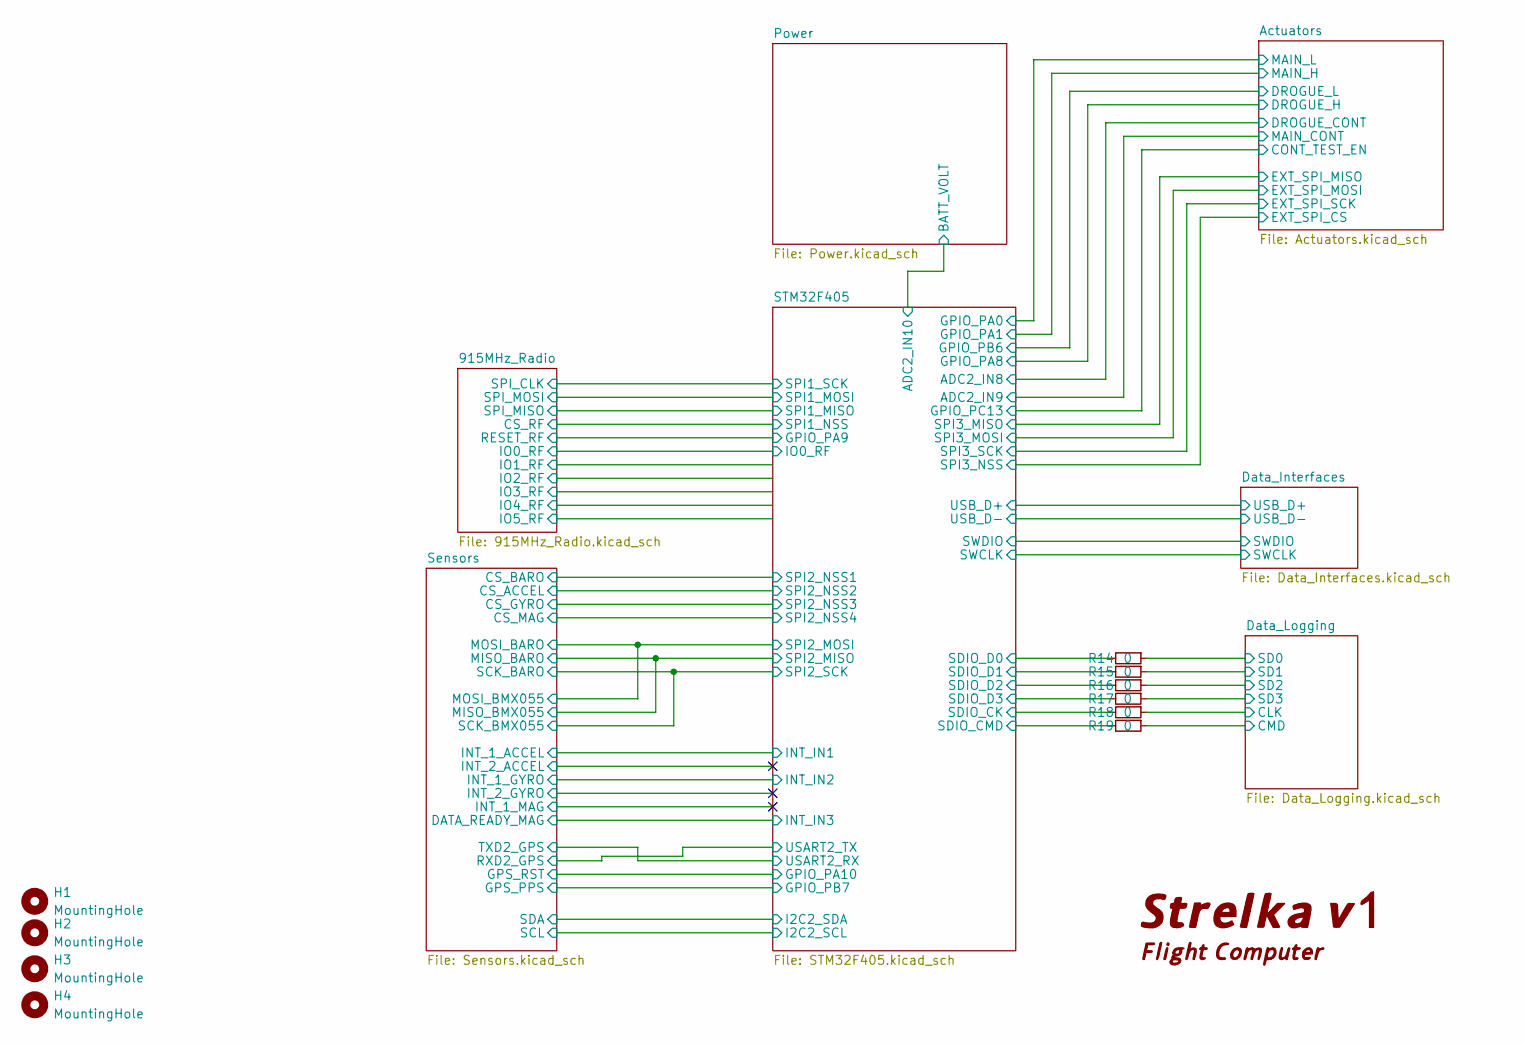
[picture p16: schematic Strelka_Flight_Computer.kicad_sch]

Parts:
H1, H2, H3, H4: MountingHole; MountingHole_2.5mm_Pad
R14, R15, R16, R17, R18, R19: 0; R_0603_1608Metric_Pad0.98x0.95mm_HandSolder

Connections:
/Data_Logging/CLK: R18.1; also elsewhere on the board
/Data_Logging/CMD: R19.1; also elsewhere on the board
/Data_Logging/SD0: R14.1; also elsewhere on the board
/Data_Logging/SD1: R15.1; also elsewhere on the board
/Data_Logging/SD2: R16.1; also elsewhere on the board
/Data_Logging/SD3: R17.1; also elsewhere on the board
/STM32F405/SDIO_CK: R18.2; also elsewhere on the board
/STM32F405/SDIO_CMD: R19.2; also elsewhere on the board
/STM32F405/SDIO_D0: R14.2; also elsewhere on the board
/STM32F405/SDIO_D1: R15.2; also elsewhere on the board
/STM32F405/SDIO_D2: R16.2; also elsewhere on the board
/STM32F405/SDIO_D3: R17.2; also elsewhere on the board

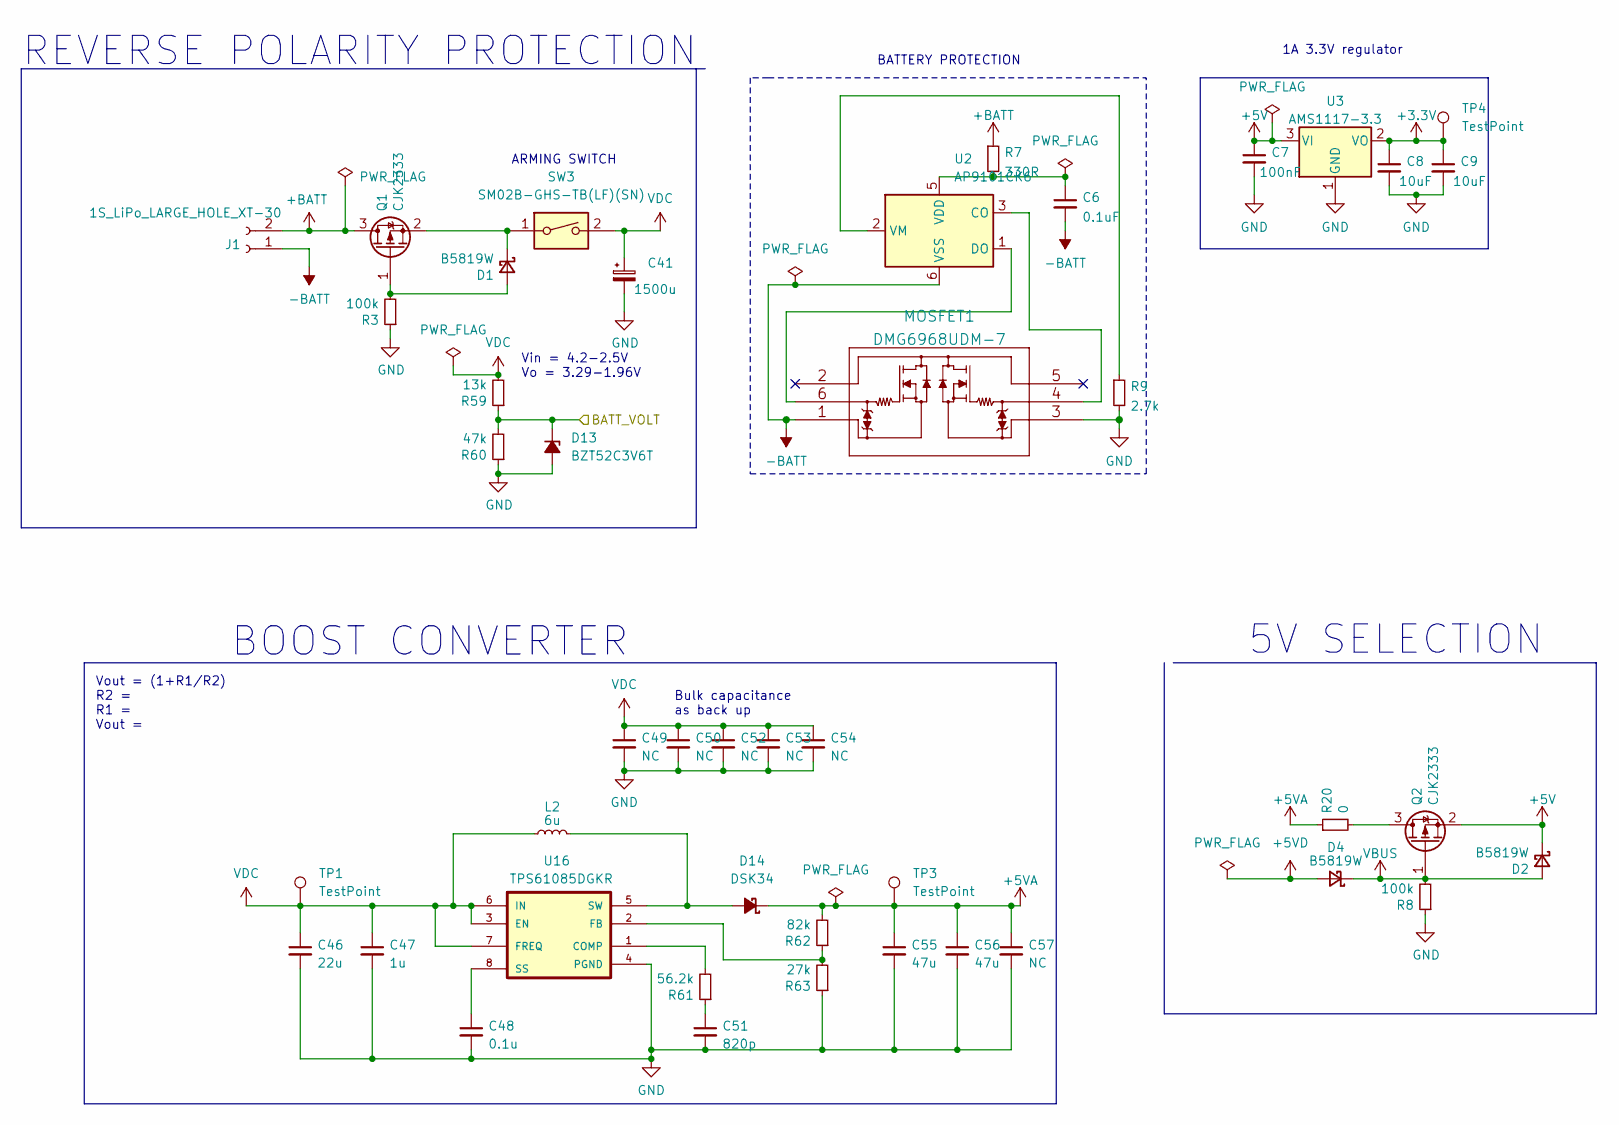
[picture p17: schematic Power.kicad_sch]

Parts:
C6: 0.1uF; C_0603_1608Metric
C7: 100nF; C_0603_1608Metric_Pad1.08x0.95mm_HandSolder
C8, C9: 10uF; C_0603_1608Metric_Pad1.08x0.95mm_HandSolder
C41: 1500u; ULR158M0JF1ARR; LCSC# C248440
C46: 22u; C_0603_1608Metric
C47: 1u; C_0603_1608Metric
C48: 0.1u; C_0603_1608Metric
C49, C50, C52, C53, C54: NC; C_0603_1608Metric
C51: 820p; C_0603_1608Metric
C55, C56: 47u; C_0805_2012Metric
C57: NC; C_0805_2012Metric
D1, D2, D4: B5819W; D_SOD-123; LCSC# C8598
D13: BZT52C3V6T; D_SOD-523; LCSC# C2858499
D14: DSK34; D_SOD-123; LCSC# C908230
J1: 1S_LiPo_LARGE_HOLE_XT-30; AMASS_XT30PW-M_1x02_P2.50mm_Horizontal
L2: 6u; L_Bourns_SRP5030T; LCSC# C1329837
MOSFET1: DMG6968UDM-7; LCSC# C151635
Q1, Q2: CJK2333; SOT-23; LCSC# C504109
R3, R8: 100k; R_0603_1608Metric
R7: 330R; R_0603_1608Metric
R9: 2.7k; R_0603_1608Metric
R20: 0; R_0603_1608Metric
R59: 13k; R_0603_1608Metric; LCSC# C137796
R60: 47k; R_0603_1608Metric; LCSC# C105579
R61: 56.2k; R_0603_1608Metric; LCSC# C105579
R62: 82k; R_0603_1608Metric; LCSC# C105579
R63: 27k; R_0603_1608Metric; LCSC# C105579
SW3: SM02B-GHS-TB(LF)(SN); SM02BGHSTBLFSN; LCSC# C189893
TP1, TP3, TP4: TestPoint; TestPoint_Pad_1.0x1.0mm
U2: AP9101CK6; SOT-23-6; LCSC# C151339
U3: AMS1117-3.3; SOT-223-3_TabPin2; LCSC# C173386
U16: TPS61085DGKR; SOP65P490X110-8N; LCSC# C113659

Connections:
+3V3: C8.1, C9.1, TP4.1, U3.2 (VO); also elsewhere on the board
+5V: C7.1, D2.1 (K), Q2.2 (S), U3.3 (VI)
+5VA: C55.1, C56.1, C57.1, D14.1 (K), R20.1, R62.2, TP3.1
+5VD: D4.2 (A); also elsewhere on the board
+BATT: J1.2, Q1.3 (D), R7.1
-BATT: C6.2, J1.1, MOSFET1.1 (S1), U2.6 (VSS)
/Power/BATT_VOLT: D13.1 (K), R59.1, R60.2; also elsewhere on the board
GND: C7.2, C8.2, C9.2, C41.2, C46.2, C47.2, C48.2, C49.2, C50.2, C51.2, C52.2, C53.2, C54.2, C55.2, C56.2, C57.2, D13.2 (A), MOSFET1.3 (S2), R3.1, R8.1, R9.2, R60.1, R63.1, U3.1 (GND), U16.4 (PGND); also elsewhere on the board
unnamed: C6.1, R7.2, U2.5 (VDD)
unnamed: C48.1, U16.8 (SS)
unnamed: C51.1, R61.1
unnamed: D1.1 (K), Q1.2 (S), SW3.1
unnamed: D1.2 (A), Q1.1 (G), R3.2
unnamed: D14.2 (A), L2.2, U16.5 (SW)
unnamed: MOSFET1.4 (G2), U2.3 (CO)
unnamed: MOSFET1.6 (G1), U2.1 (DO)
unnamed: Q2.3 (D), R20.2
unnamed: R9.1, U2.2 (VM)
unnamed: R61.2, U16.1 (COMP)
unnamed: R62.1, R63.2, U16.2 (FB)
VBUS: D2.2 (A), D4.1 (K), Q2.1 (G), R8.2; also elsewhere on the board
VDC: C41.1, C46.1, C47.1, C49.1, C50.1, C52.1, C53.1, C54.1, L2.1, R59.2, SW3.2, TP1.1, U16.3 (EN), U16.6 (IN), U16.7 (FREQ); also elsewhere on the board

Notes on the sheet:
5V SELECTION
BOOST CONVERTER
1A 3.3V regulator
REVERSE POLARITY PROTECTION
Vout = (1+R1/R2) R2 = R1 = Vout =
BATTERY PROTECTION
Bulk capacitance as back up
ARMING SWITCH
Vin = 4.2-2.5V Vo = 3.29-1.96V

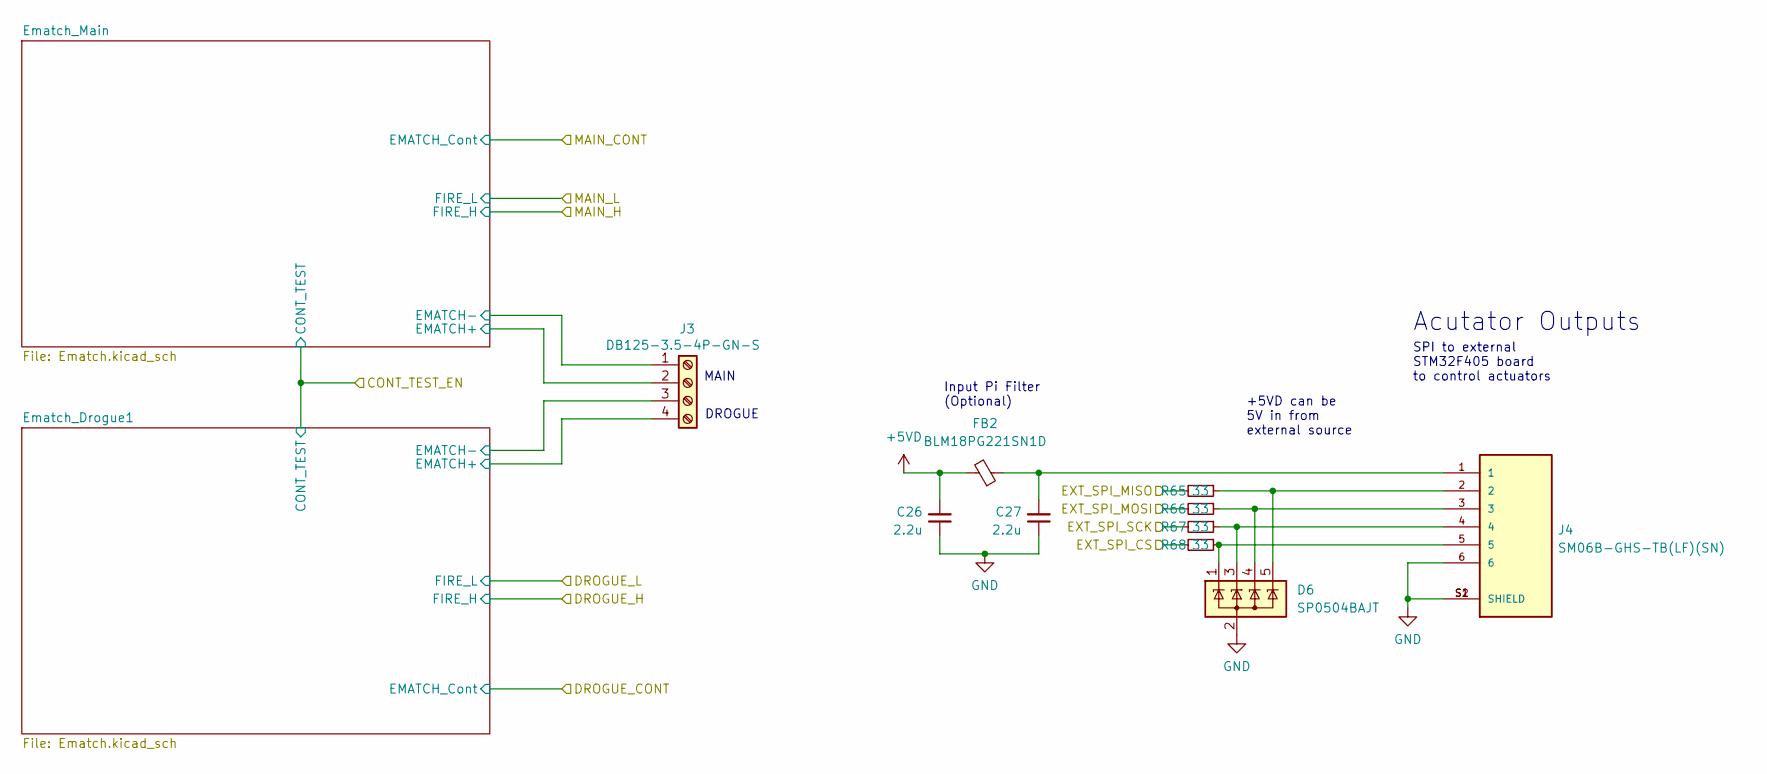
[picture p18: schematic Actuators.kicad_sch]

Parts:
C26, C27: 2.2u; C_0603_1608Metric
D6: SP0504BAJT; SOT-353_SC-70-5; LCSC# C5116451
FB2: BLM18PG221SN1D; L_0603_1608Metric; LCSC# C80165
J3: DB125-3.5-4P-GN-S; TerminalBlock_4Ucon_1x04_P3.50mm_Horizontal; LCSC# C2757925
J4: SM06B-GHS-TB(LF)(SN); JST_SM06B-GHS-TB(LF)(SN); LCSC# C133065
R65, R66, R67, R68: 33; R_0603_1608Metric_Pad0.98x0.95mm_HandSolder

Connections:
+5VD: C26.2, FB2.2; also elsewhere on the board
/Actuators/EXT_SPI_CS: R68.2; also elsewhere on the board
/Actuators/EXT_SPI_MISO: R65.2; also elsewhere on the board
/Actuators/EXT_SPI_MOSI: R66.2; also elsewhere on the board
/Actuators/EXT_SPI_SCK: R67.2; also elsewhere on the board
/Actuators/Ematch_Drogue1/EMATCH+: J3.4; also elsewhere on the board
/Actuators/Ematch_Drogue1/EMATCH-: J3.3; also elsewhere on the board
/Actuators/Ematch_Main/EMATCH+: J3.2; also elsewhere on the board
/Actuators/Ematch_Main/EMATCH-: J3.1; also elsewhere on the board
GND: C26.1, C27.1, D6.2 (A), J4.6, J4.S1 (SHIELD), J4.S2 (SHIELD); also elsewhere on the board
unnamed: C27.2, FB2.1, J4.1
unnamed: D6.1 (K), J4.5, R68.1
unnamed: D6.3 (K), J4.4, R67.1
unnamed: D6.4 (K), J4.3, R66.1
unnamed: D6.5 (K), J4.2, R65.1

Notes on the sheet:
DROGUE
+5VD can be 5V in from external source
Acutator Outputs
SPI to external STM32F405 board to control actuators
Input Pi Filter (Optional)
MAIN

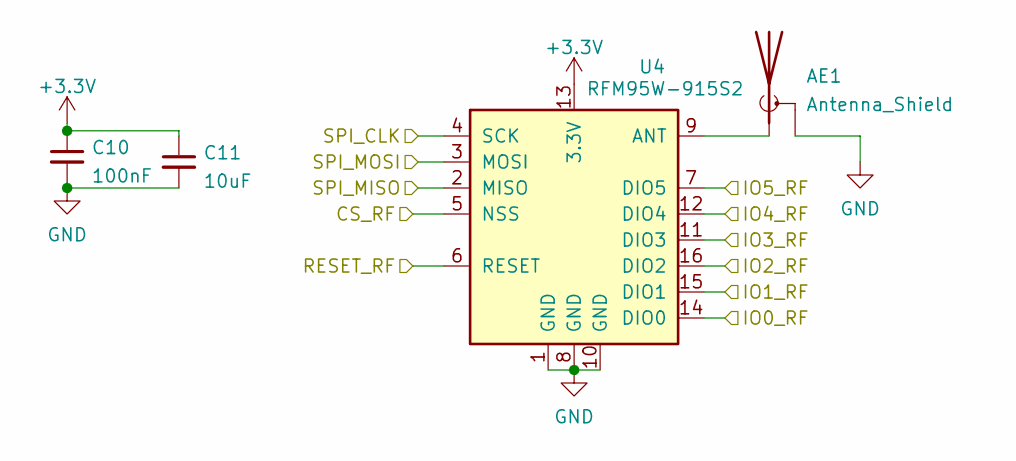
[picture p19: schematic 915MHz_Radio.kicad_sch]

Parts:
AE1: Antenna_Shield; SMA_Amphenol_132134_Vertical; LCSC# C496550
C10: 100nF; C_0603_1608Metric_Pad1.08x0.95mm_HandSolder
C11: 10uF; C_0603_1608Metric_Pad1.08x0.95mm_HandSolder
U4: RFM95W-915S2; HOPERF_RFM9XW_SMD; LCSC# C2844473

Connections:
+3V3: C10.1, C11.1, U4.13 (3.3V); also elsewhere on the board
/915MHz_Radio/CS_RF: U4.5 (NSS); also elsewhere on the board
/915MHz_Radio/IO0_RF: U4.14 (DIO0); also elsewhere on the board
/915MHz_Radio/IO1_RF: U4.15 (DIO1)
/915MHz_Radio/IO2_RF: U4.16 (DIO2)
/915MHz_Radio/IO3_RF: U4.11 (DIO3)
/915MHz_Radio/IO4_RF: U4.12 (DIO4)
/915MHz_Radio/IO5_RF: U4.7 (DIO5)
/915MHz_Radio/RESET_RF: U4.6 (RESET); also elsewhere on the board
/915MHz_Radio/SPI_CLK: U4.4 (SCK); also elsewhere on the board
/915MHz_Radio/SPI_MISO: U4.2 (MISO); also elsewhere on the board
/915MHz_Radio/SPI_MOSI: U4.3 (MOSI); also elsewhere on the board
GND: AE1.2 (Shield), C10.2, C11.2, U4.1 (GND), U4.8 (GND), U4.10 (GND); also elsewhere on the board
unnamed: AE1.1 (A), U4.9 (ANT)

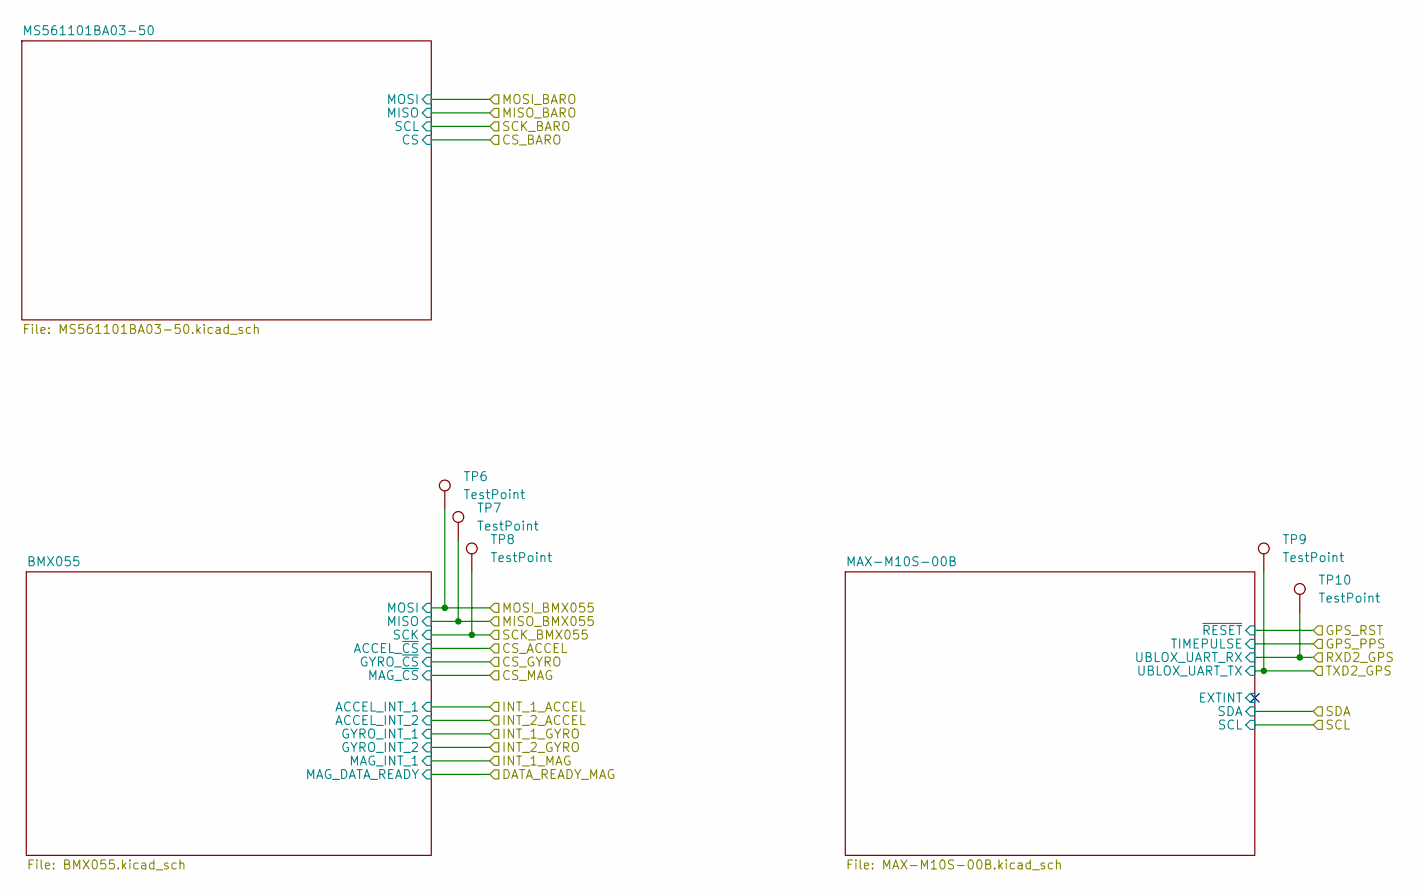
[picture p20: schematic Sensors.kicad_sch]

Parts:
TP6, TP7, TP8, TP9, TP10: TestPoint; TestPoint_Pad_1.0x1.0mm

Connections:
/STM32F405/SPI2_MISO: TP7.1; also elsewhere on the board
/STM32F405/SPI2_MOSI: TP6.1; also elsewhere on the board
/STM32F405/SPI2_SCK: TP8.1; also elsewhere on the board
/STM32F405/USART2_RX: TP9.1; also elsewhere on the board
/STM32F405/USART2_TX: TP10.1; also elsewhere on the board

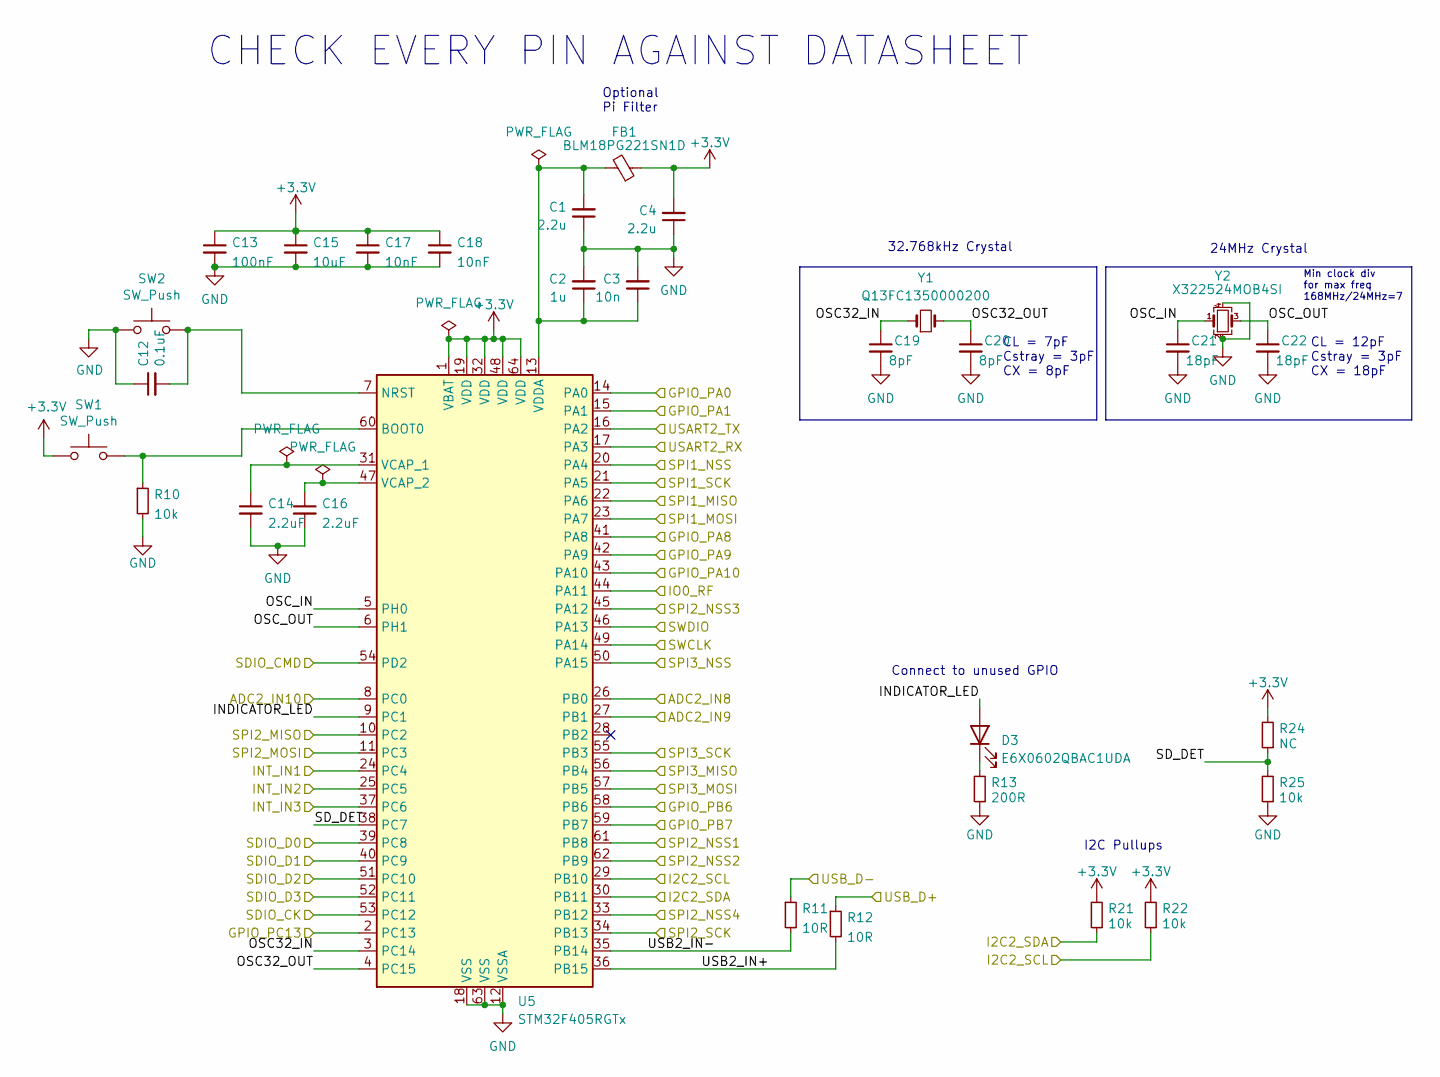
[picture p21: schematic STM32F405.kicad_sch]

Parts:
C1, C4: 2.2u; C_0603_1608Metric
C2: 1u; C_0603_1608Metric
C3: 10n; C_0603_1608Metric
C12: 0.1uF; C_0603_1608Metric_Pad1.08x0.95mm_HandSolder
C13: 100nF; C_0603_1608Metric_Pad1.08x0.95mm_HandSolder
C14, C16: 2.2uF; C_0603_1608Metric_Pad1.08x0.95mm_HandSolder
C15: 10uF; C_0603_1608Metric_Pad1.08x0.95mm_HandSolder
C17, C18: 10nF; C_0603_1608Metric_Pad1.08x0.95mm_HandSolder
C19, C20: 8pF; C_0603_1608Metric_Pad1.08x0.95mm_HandSolder
C21, C22: 18pF; C_0603_1608Metric_Pad1.08x0.95mm_HandSolder
D3: E6X0602QBAC1UDA; LED_0603_1608Metric_Pad1.05x0.95mm_HandSolder; LCSC# C375467
FB1: BLM18PG221SN1D; L_0603_1608Metric; LCSC# C80165
R10: 10k; R_0603_1608Metric
R11, R12: 10R; R_0603_1608Metric
R13: 200R; R_0603_1608Metric_Pad0.98x0.95mm_HandSolder
R21, R22, R25: 10k; R_0603_1608Metric_Pad0.98x0.95mm_HandSolder
R24: NC; R_0603_1608Metric_Pad0.98x0.95mm_HandSolder
SW1, SW2: SW_Push; SW_Push_SPST_NO_Alps_SKRK
U5: STM32F405RGTx; LQFP-64_10x10mm_P0.5mm; LCSC# C15742
Y1: Q13FC1350000200; Crystal_SMD_3215-2Pin_3.2x1.5mm; LCSC# C48615
Y2: X322524MOB4SI; Crystal_SMD_3225-4Pin_3.2x2.5mm; LCSC# C70590

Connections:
+3V3: C4.2, C13.1, C15.1, C17.1, C18.1, FB1.1, R21.2, R22.2, R24.2, SW1.1, U5.1 (VBAT), U5.19 (VDD), U5.32 (VDD), U5.48 (VDD), U5.64 (VDD); also elsewhere on the board
/915MHz_Radio/CS_RF: U5.20 (PA4); also elsewhere on the board
/915MHz_Radio/IO0_RF: U5.44 (PA11); also elsewhere on the board
/915MHz_Radio/RESET_RF: U5.42 (PA9); also elsewhere on the board
/915MHz_Radio/SPI_CLK: U5.21 (PA5); also elsewhere on the board
/915MHz_Radio/SPI_MISO: U5.22 (PA6); also elsewhere on the board
/915MHz_Radio/SPI_MOSI: U5.23 (PA7); also elsewhere on the board
/Actuators/CONT_TEST_EN: U5.2 (PC13); also elsewhere on the board
/Actuators/DROGUE_CONT: U5.26 (PB0); also elsewhere on the board
/Actuators/DROGUE_H: U5.41 (PA8); also elsewhere on the board
/Actuators/DROGUE_L: U5.58 (PB6); also elsewhere on the board
/Actuators/EXT_SPI_CS: U5.50 (PA15); also elsewhere on the board
/Actuators/EXT_SPI_MISO: U5.56 (PB4); also elsewhere on the board
/Actuators/EXT_SPI_MOSI: U5.57 (PB5); also elsewhere on the board
/Actuators/EXT_SPI_SCK: U5.55 (PB3); also elsewhere on the board
/Actuators/MAIN_CONT: U5.27 (PB1); also elsewhere on the board
/Actuators/MAIN_H: U5.15 (PA1); also elsewhere on the board
/Actuators/MAIN_L: U5.14 (PA0); also elsewhere on the board
/Data_Interfaces/SWCLK: U5.49 (PA14); also elsewhere on the board
/Data_Interfaces/SWDIO: U5.46 (PA13); also elsewhere on the board
/Data_Interfaces/USB_D+: R12.1; also elsewhere on the board
/Data_Interfaces/USB_D-: R11.1; also elsewhere on the board
/Power/BATT_VOLT: U5.8 (PC0); also elsewhere on the board
/STM32F405/GPIO_PA10: U5.43 (PA10); also elsewhere on the board
/STM32F405/GPIO_PB7: U5.59 (PB7); also elsewhere on the board
/STM32F405/I2C2_SCL: R22.1, U5.29 (PB10); also elsewhere on the board
/STM32F405/I2C2_SDA: R21.1, U5.30 (PB11); also elsewhere on the board
/STM32F405/INDICATOR_LED: D3.2 (A), U5.9 (PC1)
/STM32F405/INT_IN1: U5.24 (PC4); also elsewhere on the board
/STM32F405/INT_IN2: U5.25 (PC5); also elsewhere on the board
/STM32F405/INT_IN3: U5.37 (PC6); also elsewhere on the board
/STM32F405/OSC32_IN: C19.1, U5.3 (PC14), Y1.1
/STM32F405/OSC32_OUT: C20.1, U5.4 (PC15), Y1.2
/STM32F405/OSC_IN: C21.1, U5.5 (PH0), Y2.1
/STM32F405/OSC_OUT: C22.1, U5.6 (PH1), Y2.3
/STM32F405/SDIO_CK: U5.53 (PC12); also elsewhere on the board
/STM32F405/SDIO_CMD: U5.54 (PD2); also elsewhere on the board
/STM32F405/SDIO_D0: U5.39 (PC8); also elsewhere on the board
/STM32F405/SDIO_D1: U5.40 (PC9); also elsewhere on the board
/STM32F405/SDIO_D2: U5.51 (PC10); also elsewhere on the board
/STM32F405/SDIO_D3: U5.52 (PC11); also elsewhere on the board
/STM32F405/SD_DET: R24.1, R25.2, U5.38 (PC7)
/STM32F405/SPI2_MISO: U5.10 (PC2); also elsewhere on the board
/STM32F405/SPI2_MOSI: U5.11 (PC3); also elsewhere on the board
/STM32F405/SPI2_NSS1: U5.61 (PB8); also elsewhere on the board
/STM32F405/SPI2_NSS2: U5.62 (PB9); also elsewhere on the board
/STM32F405/SPI2_NSS3: U5.45 (PA12); also elsewhere on the board
/STM32F405/SPI2_NSS4: U5.33 (PB12); also elsewhere on the board
/STM32F405/SPI2_SCK: U5.34 (PB13); also elsewhere on the board
/STM32F405/USART2_RX: U5.17 (PA3); also elsewhere on the board
/STM32F405/USART2_TX: U5.16 (PA2); also elsewhere on the board
/STM32F405/USB2_IN+: R12.2, U5.36 (PB15)
/STM32F405/USB2_IN-: R11.2, U5.35 (PB14)
GND: C1.1, C2.2, C3.2, C4.1, C12.1, C13.2, C14.2, C15.2, C16.2, C17.2, C18.2, C19.2, C20.2, C21.2, C22.2, R10.2, R13.1, R25.1, SW2.1, U5.12 (VSSA), U5.18 (VSS), U5.63 (VSS), Y2.2, Y2.4; also elsewhere on the board
unnamed: C1.2, C2.1, C3.1, FB1.2, U5.13 (VDDA)
unnamed: C12.2, SW2.2, U5.7 (NRST)
unnamed: C14.1, U5.31 (VCAP_1)
unnamed: C16.1, U5.47 (VCAP_2)
unnamed: D3.1 (K), R13.2
unnamed: R10.1, SW1.2, U5.60 (BOOT0)

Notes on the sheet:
Connect to unused GPIO
24MHz Crystal
CL = 7pF Cstray = 3pF CX = 8pF
32.768kHz Crystal
I2C Pullups
CHECK EVERY PIN AGAINST DATASHEET
CL = 12pF Cstray = 3pF CX = 18pF
Optional Pi Filter
Min clock div for max freq 168MHz/24MHz=7

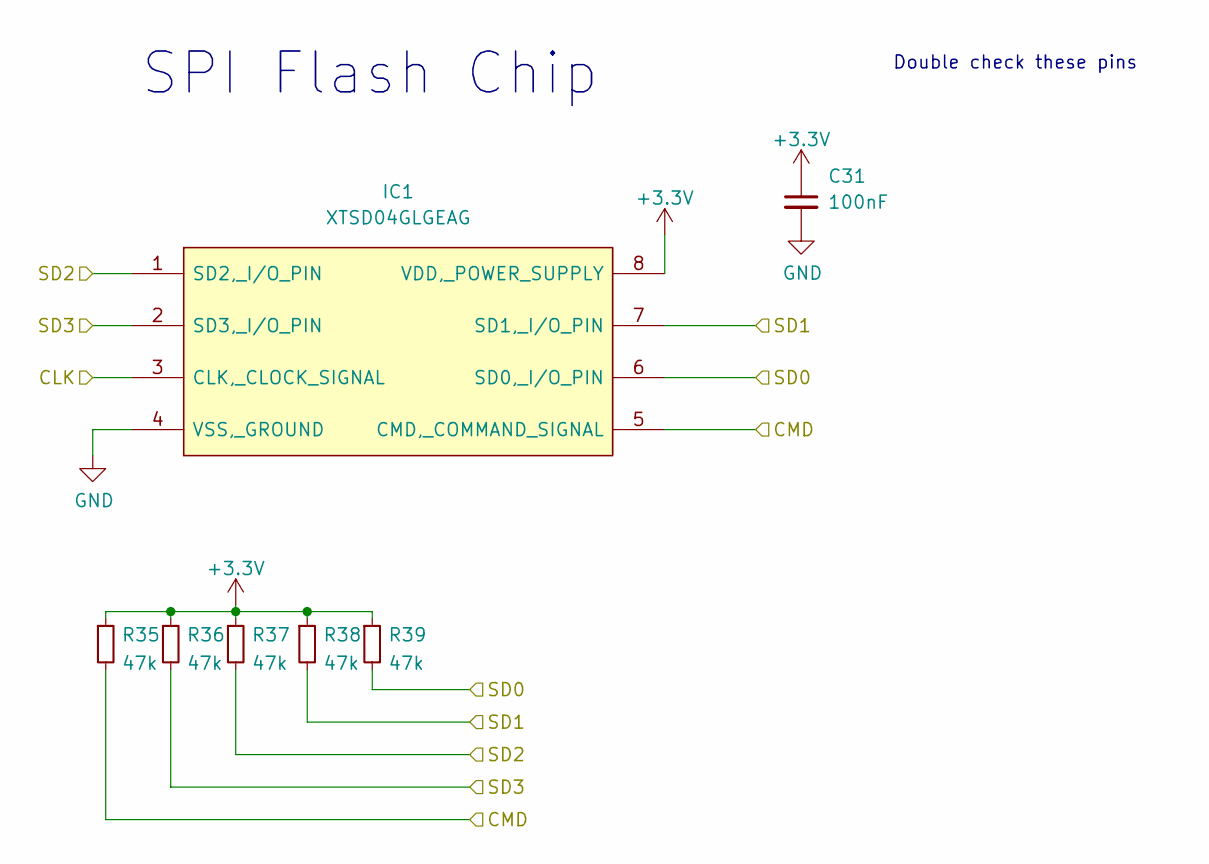
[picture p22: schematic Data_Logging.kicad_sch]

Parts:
C31: 100nF; C_0603_1608Metric
IC1: XTSD04GLGEAG; SON127P800X600X95-8N; LCSC# C558839
R35, R36, R37, R38, R39: 47k; R_0603_1608Metric

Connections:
+3V3: C31.1, IC1.8 (VDD,_POWER_SUPPLY), R35.1, R36.1, R37.1, R38.1, R39.1; also elsewhere on the board
/Data_Logging/CLK: IC1.3 (CLK,_CLOCK_SIGNAL); also elsewhere on the board
/Data_Logging/CMD: IC1.5 (CMD,_COMMAND_SIGNAL), R35.2; also elsewhere on the board
/Data_Logging/SD0: IC1.6 (SD0,_I/O_PIN), R39.2; also elsewhere on the board
/Data_Logging/SD1: IC1.7 (SD1,_I/O_PIN), R38.2; also elsewhere on the board
/Data_Logging/SD2: IC1.1 (SD2,_I/O_PIN), R37.2; also elsewhere on the board
/Data_Logging/SD3: IC1.2 (SD3,_I/O_PIN), R36.2; also elsewhere on the board
GND: C31.2, IC1.4 (VSS,_GROUND); also elsewhere on the board

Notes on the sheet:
SPI Flash Chip
Double check these pins

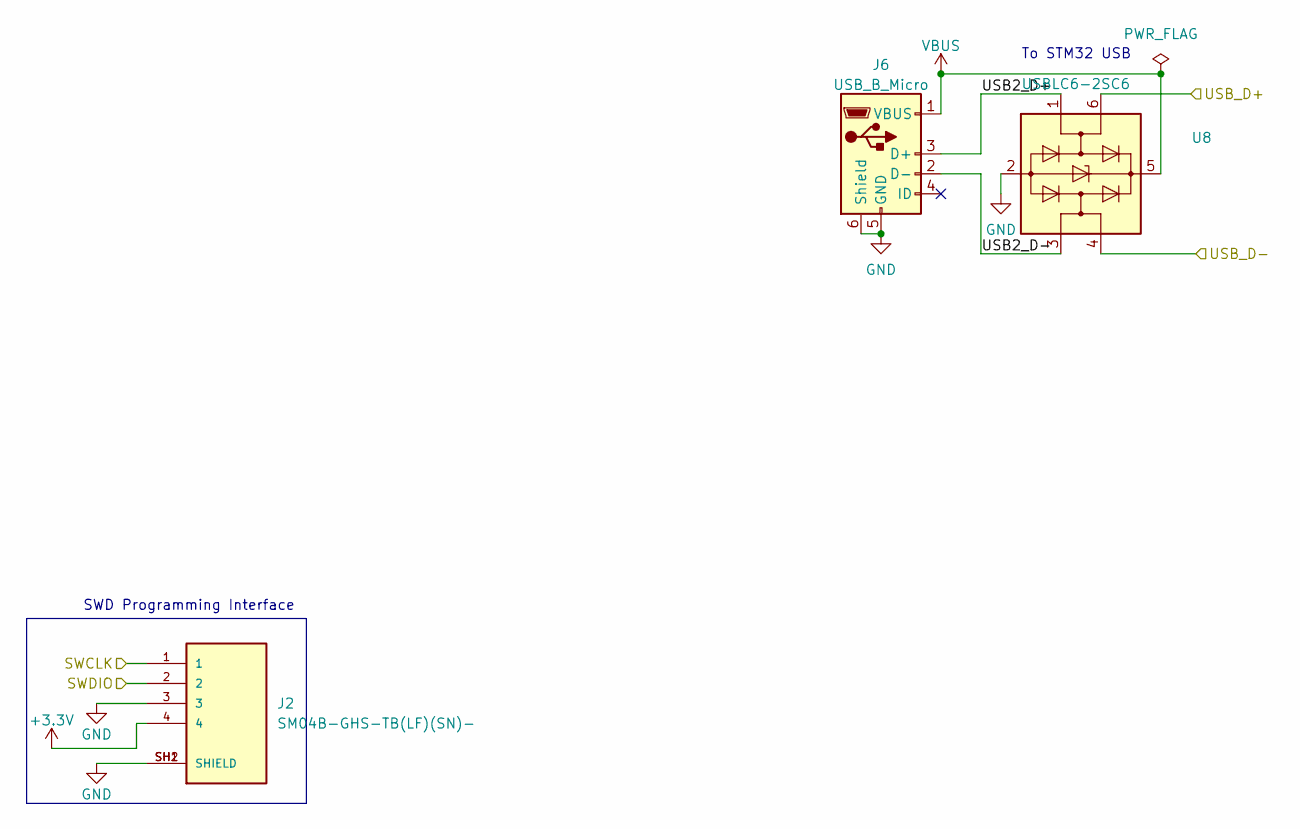
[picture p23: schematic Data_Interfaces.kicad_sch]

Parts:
J2: SM04B-GHS-TB(LF)(SN)-; JST_SM04B-GHS-TB(LF)(SN)-; LCSC# C189895
J6: USB_B_Micro; USB_Micro-B_Molex-105017-0001
U8: USBLC6-2SC6; SOT-23-6; LCSC# C2687116

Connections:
+3V3: J2.4; also elsewhere on the board
/Data_Interfaces/SWCLK: J2.1; also elsewhere on the board
/Data_Interfaces/SWDIO: J2.2; also elsewhere on the board
/Data_Interfaces/USB2_D+: J6.3 (D+), U8.1 (I/O1)
/Data_Interfaces/USB2_D-: J6.2 (D-), U8.3 (I/O2)
/Data_Interfaces/USB_D+: U8.6 (I/O1); also elsewhere on the board
/Data_Interfaces/USB_D-: U8.4 (I/O2); also elsewhere on the board
GND: J2.3, J2.SH1 (SHIELD), J2.SH2 (SHIELD), J6.5 (GND), J6.6 (Shield), U8.2 (GND); also elsewhere on the board
VBUS: J6.1 (VBUS), U8.5 (VBUS); also elsewhere on the board

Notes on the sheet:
To STM32 USB
SWD Programming Interface

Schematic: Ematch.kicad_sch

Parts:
D9: 1SS388; D_SOD-523; LCSC# C2987059
I2: AL5809-30S1-7; D_SOD-123; LCSC# C151325
Q8, Q9: AO3401A; SOT-23; LCSC# C347476
Q10: AP2300; SOT-23; LCSC# C360338
Q11: MMBT2222; SOT-23; LCSC# C8512
R47: 2R; R_2512_6332Metric; LCSC# C91926
R48, R51, R53, R54: 1k; R_0603_1608Metric
R49, R50, R52, R69: 100k; R_0603_1608Metric
U15: LM321; SOT-23-5; LCSC# C5189111

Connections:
+3V3: Q8.2 (S), R69.2, U15.2 (V-); also elsewhere on the board
/Actuators/CONT_TEST_EN: R48.2, R69.1; also elsewhere on the board
/Actuators/Ematch_Main/EMATCH+: D9.1 (K), Q9.3 (D), U15.1 (+); also elsewhere on the board
/Actuators/Ematch_Main/EMATCH-: Q10.3 (D); also elsewhere on the board
/Actuators/MAIN_CONT: R52.1, U15.4; also elsewhere on the board
/Actuators/MAIN_H: R53.2; also elsewhere on the board
/Actuators/MAIN_L: R50.2, R51.1; also elsewhere on the board
GND: Q10.2 (S), Q11.3 (E), R50.1, R54.1, U15.5 (V+); also elsewhere on the board
unnamed: D9.2 (A), I2.2
unnamed: I2.1, Q8.3 (D)
unnamed: Q8.1 (G), R48.1
unnamed: Q9.2 (S), R47.2
unnamed: Q10.1 (G), R51.2
unnamed: Q11.1 (B), R53.1
unnamed: Q9.1 (G), Q11.2 (C), R49.1
unnamed: R52.2, R54.2, U15.3 (-)
VDC: R47.1, R49.2; also elsewhere on the board

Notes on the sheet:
Continuity Test
Verify STM32 pins do not do weird shit at boot
Battery voltage applied
R_ematch: 1-2 Ohm R_limit = 2.0 Ohm Batt volt = 3V - 4.2V Fire current: Batt volt = 3.0V: R_ematch = 1 Ohm, I = 1.5A R_ematch = 2 Ohm, I = 0.75A Batt volt = 4.2V: R_ematch = 1 Ohm, I = 1.4AA R_ematch = 2 Ohm, I = 1.05A
To connector
Ematch Actuation

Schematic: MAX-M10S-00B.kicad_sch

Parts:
AE2: Antenna_Shield; U.FL_Hirose_U.FL-R-SMT-1_Vertical; LCSC# C88373
BT2: MS621FE-FL11E; BAT_MS621FE-FL11E
C36: 100n; C_0603_1608Metric
C37: NC; C_0402_1005Metric
C38: 4.7u; C_0603_1608Metric
C39: 100nF; C_0603_1608Metric
C40: 10uF; C_0603_1608Metric
D10: ESD9B3.3ST5G; D_0402_1005Metric; LCSC# C558621
D11: BAT54C; SOT-23; LCSC# C37704
D12: LED_BLUE; LED_0603_1608Metric
FB3: HZ1005K182TFB03; R_0402_1005Metric; LCSC# C279553
IC2: MAX-M10S-00B; MAXM10S00B
JP2: UART_Switch
R55: 0R; R_0402_1005Metric
R56, R57: 1k; R_0603_1608Metric
R58: 0R; R_0603_1608Metric

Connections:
+3V3: C39.1, C40.1, D11.1, IC2.7 (V_IO), IC2.8 (VCC); also elsewhere on the board
/STM32F405/GPIO_PA10: IC2.9 (RESET_N); also elsewhere on the board
/STM32F405/GPIO_PB7: R58.2; also elsewhere on the board
/STM32F405/I2C2_SCL: IC2.17 (SCL); also elsewhere on the board
/STM32F405/I2C2_SDA: IC2.16 (SDA); also elsewhere on the board
/STM32F405/USART2_RX: JP2.2 (TX1); also elsewhere on the board
/STM32F405/USART2_TX: JP2.4 (RX2); also elsewhere on the board
/Sensors/MAX-M10S-00B/EXTINT: IC2.5 (EXTINT)
/Sensors/MAX-M10S-00B/PPS: IC2.4 (TIMEPULSE), R57.1, R58.1
/Sensors/MAX-M10S-00B/RF_IN: AE2.1 (A), D10.2 (A2), FB3.1, IC2.11 (RF_IN)
/Sensors/MAX-M10S-00B/VCC_RF: C37.1, IC2.14 (VCC_RF), R55.1
/Sensors/MAX-M10S-00B/V_BKCP: BT2.+ (r~), C36.1, C38.1, IC2.6 (V_BCKP), R56.1
GND: AE2.2 (Shield), BT2.-, C36.2, C37.2, C38.2, C39.2, C40.2, D10.1 (A1), D12.1 (K), IC2.1 (GND_1), IC2.10 (GND_2), IC2.12 (GND_3); also elsewhere on the board
unnamed: D11.3, R56.2
unnamed: D12.2 (A), R57.2
unnamed: FB3.2, R55.2
unnamed: IC2.2 (TXD), JP2.3 (TX1)
unnamed: IC2.3 (RXD), JP2.1 (RX1)

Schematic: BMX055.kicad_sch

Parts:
C28, C29: 100nF; C_0603_1608Metric
R40: 0R; R_0603_1608Metric
U11: BMX055; LCSC# C94022

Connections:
+3V3: C28.1, C29.1, U11.3 (VDD), U11.13 (VDDIO); also elsewhere on the board
/STM32F405/INT_IN1: U11.19 (INT1); also elsewhere on the board
/STM32F405/INT_IN2: U11.14 (INT3); also elsewhere on the board
/STM32F405/INT_IN3: U11.2 (DRDYM); also elsewhere on the board
/STM32F405/SPI2_MISO: U11.12 (SDO2), U11.17 (SDO1); also elsewhere on the board
/STM32F405/SPI2_MOSI: U11.11 (SDX); also elsewhere on the board
/STM32F405/SPI2_NSS2: U11.16 (CSB1); also elsewhere on the board
/STM32F405/SPI2_NSS3: U11.5 (CSB2); also elsewhere on the board
/STM32F405/SPI2_NSS4: U11.20 (CSB3); also elsewhere on the board
/STM32F405/SPI2_SCK: U11.9 (SCX); also elsewhere on the board
/Sensors/INT_1_MAG: U11.10 (INT5)
/Sensors/INT_2_ACCEL: U11.1 (INT2)
/Sensors/INT_2_GYRO: U11.15 (INT4)
GND: C28.2, C29.2, R40.2, U11.4 (GNDA), U11.6 (GNDIO); also elsewhere on the board
unnamed: R40.1, U11.7 (PS)

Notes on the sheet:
Mag/Gyro/Accel
Tied low for SPI interface selection
Features: - Triaxial 16bit gyroscope - orientation- & motion inactivity recognition - Ranges switchable from ±125°/s to ±2000°/s - Low-pass filter bandwidths 230Hz - 12Hz - Integrated FIFO with a depth of 100 frames - Motion-triggered interrupt-signal generation - new data - any-motion (slope) dete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

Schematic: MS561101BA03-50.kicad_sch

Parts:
C30: 100nF; C_0603_1608Metric
U12: MS561101BA03-50

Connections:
+3V3: C30.1, U12.1 (VDD); also elsewhere on the board
/STM32F405/SPI2_MISO: U12.6 (SDO); also elsewhere on the board
/STM32F405/SPI2_MOSI: U12.7 (SDI/SDA); also elsewhere on the board
/STM32F405/SPI2_NSS1: U12.4 (CSB), U12.5 (CSB); also elsewhere on the board
/STM32F405/SPI2_SCK: U12.8 (SCLK); also elsewhere on the board
GND: C30.2, U12.2 (PS), U12.3 (GND); also elsewhere on the board

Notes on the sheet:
Barometer
Features: - Range 10-1200mbar +20,000m - -1449.98m - Resolution 24bit - Accuracy +-1.5mbar - Resolution 0.065 / 0.042 / 0.027 / 0.018 / 0.012mbar - Error band +-3.5mbar - Altitude res 0.1m

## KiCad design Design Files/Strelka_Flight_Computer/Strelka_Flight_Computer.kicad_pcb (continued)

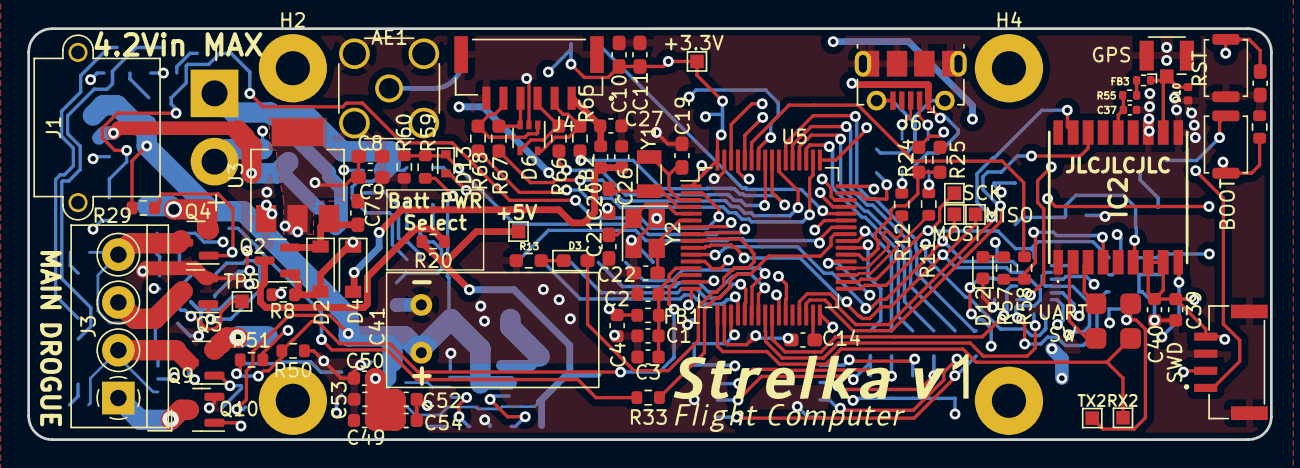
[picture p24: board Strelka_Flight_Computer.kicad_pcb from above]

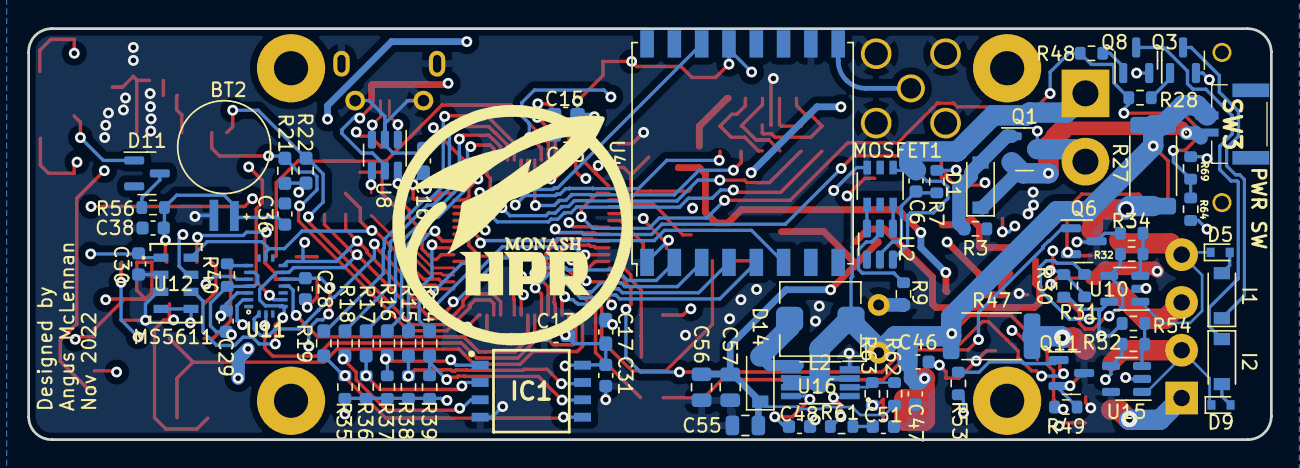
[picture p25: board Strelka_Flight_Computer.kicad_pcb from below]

Board: 4 copper layers, 91.0 x 30.1 mm, 168 parts (79 on the bottom side), 123 nets.

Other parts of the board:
D5: 1SS388; D_SOD-523
I1: AL5809-30S1-7; D_SOD-123
Q3, Q4: AO3401A; SOT-23
Q5: AP2300; SOT-23
Q6: MMBT2222; SOT-23
R27: 2R; R_2512_6332Metric
R28, R31, R33, R34: 1k; R_0603_1608Metric
R29, R30, R32, R64: 100k; R_0603_1608Metric
TP5: TestPoint; TestPoint_Pad_1.0x1.0mm
U10: LM321; SOT-23-5

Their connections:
+3V3: Q3.2 (S), R64.2, U10.2 (V-); also elsewhere on the board
/Actuators/CONT_TEST_EN: R28.2, R64.1; also elsewhere on the board
/Actuators/DROGUE_CONT: R32.1, TP5.1, U10.4; also elsewhere on the board
/Actuators/DROGUE_H: R33.2; also elsewhere on the board
/Actuators/DROGUE_L: R30.2, R31.1; also elsewhere on the board
/Actuators/Ematch_Drogue1/EMATCH+: D5.1 (K), Q4.3 (D), U10.1 (+); also elsewhere on the board
/Actuators/Ematch_Drogue1/EMATCH-: Q5.3 (D); also elsewhere on the board
GND: Q5.2 (S), Q6.3 (E), R30.1, R34.1, U10.5 (V+); also elsewhere on the board
unnamed: D5.2 (A), I1.2
unnamed: I1.1, Q3.3 (D)
unnamed: Q3.1 (G), R28.1
unnamed: Q4.1 (G), Q6.2 (C), R29.1
unnamed: Q4.2 (S), R27.2
unnamed: Q5.1 (G), R31.2
unnamed: Q6.1 (B), R33.1
unnamed: R32.2, R34.2, U10.3 (-)
VDC: R27.1, R29.2; also elsewhere on the board

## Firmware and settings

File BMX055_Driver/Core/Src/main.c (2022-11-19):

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
/* Includes ------------------------------------------------------------------*/
#include "main.h"
#include "cmsis_os.h"
#include "fatfs.h"
#include "usb_device.h"

/* USER CODE BEGIN Includes */
#include "BMX055.h"
/* USER CODE END Includes */

ADC_HandleTypeDef hadc2;

CRC_HandleTypeDef hcrc;

I2C_HandleTypeDef hi2c2;

SD_HandleTypeDef hsd;

SPI_HandleTypeDef hspi1;
SPI_HandleTypeDef hspi2;
SPI_HandleTypeDef hspi3;

TIM_HandleTypeDef htim3;

UART_HandleTypeDef huart1;
UART_HandleTypeDef huart2;

/* Definitions for defaultTask */
osThreadId_t defaultTaskHandle;
const osThreadAttr_t defaultTask_attributes = {
  .name = "defaultTask",
  .stack_size = 128 * 4,
  .priority = (osPriority_t) osPriorityNormal,
};
void SystemClock_Config(void);
static void MX_GPIO_Init(void);
static void MX_SDIO_SD_Init(void);
static void MX_SPI1_Init(void);
static void MX_SPI2_Init(void);
static void MX_USART1_UART_Init(void);
static void MX_TIM3_Init(void);
static void MX_I2C2_Init(void);
static void MX_ADC2_Init(void);
static void MX_SPI3_Init(void);
static void MX_USART2_UART_Init(void);
static void MX_CRC_Init(void);
void StartDefaultTask(void *argument);

/**
  * @brief  The application entry point.
  * @retval int
  */
int main(void)
{
  /* USER CODE BEGIN 1 */

	BMX055_Handle bmx055;
	bmx055.hspi = &hspi2;
	// Accelerometer parameters
	bmx055.acc_CS_port = GPIOC;
	bmx055.acc_CS_pin = ACCEL_CS_Pin;
	bmx055.acc_range = BMX055_ACC_RANGE_4;
	bmx055.acc_bandwidth = BMX055_ACC_PMU_BW_7_81;

	// Gyroscope parameters
	bmx055.gyro_CS_port = GPIOC;
	bmx055.gyro_CS_pin = GYRO_CS_Pin;
	bmx055.acc_range = BMX055_GYRO_RANGE_32_8;
	bmx055.acc_bandwidth = BMX055_GYRO_BW_64;

	// Magnetometer parameters
	bmx055.mag_CS_port = GPIOC;
	bmx055.mag_CS_pin = MAG_CS_Pin;
	bmx055.mag_data_rate = BMX055_MAG_DATA_RATE_30;

	// Init BMX055
	if(!BMX055_init(&bmx055)) {
		printf("[main] BMX055 failed to start\r\n");
	}
  /* USER CODE END 1 */

  /* MCU Configuration--------------------------------------------------------*/

  /* Reset of all peripherals, Initializes the Flash interface and the Systick. */
  HAL_Init();

  /* Configure the system clock */
  SystemClock_Config();

  /* Initialize all configured peripherals */
  MX_GPIO_Init();
  MX_SDIO_SD_Init();
  MX_SPI1_Init();
  MX_SPI2_Init();
  MX_USART1_UART_Init();
  MX_TIM3_Init();
  MX_FATFS_Init();
  MX_I2C2_Init();
  MX_ADC2_Init();
  MX_SPI3_Init();
  MX_USART2_UART_Init();
  MX_CRC_Init();
  /* Init scheduler */
  osKernelInitialize();

  /* USER CODE BEGIN RTOS_MUTEX */
  /* add mutexes, ... */
  /* USER CODE END RTOS_MUTEX */

  /* USER CODE BEGIN RTOS_SEMAPHORES */
  /* add semaphores, ... */
  /* USER CODE END RTOS_SEMAPHORES */

  /* USER CODE BEGIN RTOS_TIMERS */
  /* start timers, add new ones, ... */
  /* USER CODE END RTOS_TIMERS */

  /* USER CODE BEGIN RTOS_QUEUES */
  /* add queues, ... */
  /* USER CODE END RTOS_QUEUES */

  /* Create the thread(s) */
  /* creation of defaultTask */
  defaultTaskHandle = osThreadNew(StartDefaultTask, NULL, &defaultTask_attributes);

  /* USER CODE BEGIN RTOS_THREADS */
  /* add threads, ... */
  /* USER CODE END RTOS_THREADS */

  /* USER CODE BEGIN RTOS_EVENTS */
  /* add events, ... */
  /* USER CODE END RTOS_EVENTS */

  /* Start scheduler */
  osKernelStart();

  /* We should never get here as control is now taken by the scheduler */
  /* Infinite loop */
  /* USER CODE BEGIN WHILE */
  while (1)
  {
    /* USER CODE END WHILE */

    /* USER CODE BEGIN 3 */
  }
  /* USER CODE END 3 */
}

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
/* USER CODE BEGIN Header_StartDefaultTask */
/**
  * @brief  Function implementing the defaultTask thread.
  * @param  argument: Not used
  * @retval None
  */
/* USER CODE END Header_StartDefaultTask */
void StartDefaultTask(void *argument)
{
  /* init code for USB_DEVICE */
  MX_USB_DEVICE_Init();
  /* USER CODE BEGIN 5 */
  /* Infinite loop */
  for(;;)
  {
    osDelay(1);
  }
  /* USER CODE END 5 */
}

/**
  * @brief  This function is executed in case of error occurrence.
  * @retval None
  */
void Error_Handler(void)
{
  /* USER CODE BEGIN Error_Handler_Debug */
  /* User can add his own implementation to report the HAL error return state */
  __disable_irq();
  while (1)
  {
  }
  /* USER CODE END Error_Handler_Debug */
}

#ifdef  USE_FULL_ASSERT
/**
  * @brief  Reports the name of the source file and the source line number
  *         where the assert_param error has occurred.
  * @param  file: pointer to the source file name
  * @param  line: assert_param error line source number
  * @retval None
  */
void assert_failed(uint8_t *file, uint32_t line)
{
  /* USER CODE BEGIN 6 */
  /* User can add his own implementation to report the file name and line number,
     ex: printf("Wrong parameters value: file %s on line %d\r\n", file, line) */
  /* USER CODE END 6 */
}
#endif /* USE_FULL_ASSERT */

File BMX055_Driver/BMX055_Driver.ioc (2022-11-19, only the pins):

Mcu.UserName=STM32F405RGTx
PA0-WKUP.GPIO_Label=MAIN_L
PA0-WKUP.Signal=GPIO_Output
PA1.GPIO_Label=MAIN_H
PA1.Signal=GPIO_Output
PA10.Signal=USART1_RX
PA11.GPIO_Label=IO_RF
PA11.Signal=GPXTI11
PA12.GPIO_Label=GYRO_CS
PA12.Signal=GPIO_Output
PA13.Signal=SYS_JTMS-SWDIO
PA14.Signal=SYS_JTCK-SWCLK
PA15.Signal=SPI3_NSS
PA2.Signal=USART2_TX
PA3.Signal=USART2_RX
PA4.Signal=SPI1_NSS
PA5.Signal=SPI1_SCK
PA6.Signal=SPI1_MISO
PA7.Signal=SPI1_MOSI
PA8.GPIO_Label=DROGUE_H
PA8.Signal=GPIO_Output
PA9.Signal=USART1_TX
PB0.GPIO_Label=DROGUE_CONT
PB0.Signal=ADCx_IN8
PB1.GPIO_Label=MAIN_CONT
PB1.Signal=ADCx_IN9
PB10.Signal=I2C2_SCL
PB11.Signal=I2C2_SDA
PB12.GPIO_Label=MAG_CS
PB12.Signal=GPIO_Output
PB13.Signal=SPI2_SCK
PB14.Signal=USB_OTG_HS_DM
PB15.Signal=USB_OTG_HS_DP
PB3.Signal=SPI3_SCK
PB4.Signal=SPI3_MISO
PB5.Signal=SPI3_MOSI
PB6.GPIO_Label=DROGUE_L
PB6.Signal=GPIO_Output
PB7.GPIO_Label=GPS_PPS
PB7.Signal=GPXTI7
PB8.GPIO_Label=BARO_CS
PB8.Signal=GPIO_Output
PB9.GPIO_Label=ACCEL_CS
PB9.Signal=GPIO_Output
PC0.GPIO_Label=BATT_VOLT_READ
PC0.Signal=ADCx_IN10
PC1.GPIO_Label=LED_INDICATOR
PC1.Signal=GPIO_Output
PC10.Signal=SDIO_D2
PC11.Signal=SDIO_D3
PC12.Signal=SDIO_CK
PC13-ANTI_TAMP.GPIO_Label=CONT_TEST_EN
PC13-ANTI_TAMP.Signal=GPIO_Output
PC14-OSC32_IN.Signal=RCC_OSC32_IN
PC15-OSC32_OUT.Signal=RCC_OSC32_OUT
PC2.Signal=SPI2_MISO
PC3.Signal=SPI2_MOSI
PC4.GPIO_Label=ACCEL_INT
PC4.Signal=GPXTI4
PC5.GPIO_Label=GYRO_INT
PC5.Signal=GPXTI5
PC6.GPIO_Label=MAG_INT
PC6.Signal=GPXTI6
PC7.GPIO_Label=SD_DET
PC7.Signal=GPIO_Input
PC8.Signal=SDIO_D0
PC9.Signal=SDIO_D1
PD2.Signal=SDIO_CMD
PH0-OSC_IN.Signal=RCC_OSC_IN
PH1-OSC_OUT.Signal=RCC_OSC_OUT

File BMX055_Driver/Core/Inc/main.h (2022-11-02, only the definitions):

#define CONT_TEST_EN_Pin GPIO_PIN_13
#define CONT_TEST_EN_GPIO_Port GPIOC
#define BATT_VOLT_READ_Pin GPIO_PIN_0
#define BATT_VOLT_READ_GPIO_Port GPIOC
#define LED_INDICATOR_Pin GPIO_PIN_1
#define LED_INDICATOR_GPIO_Port GPIOC
#define MAIN_L_Pin GPIO_PIN_0
#define MAIN_L_GPIO_Port GPIOA
#define MAIN_H_Pin GPIO_PIN_1
#define MAIN_H_GPIO_Port GPIOA
#define ACCEL_INT_Pin GPIO_PIN_4
#define ACCEL_INT_GPIO_Port GPIOC
#define GYRO_INT_Pin GPIO_PIN_5
#define GYRO_INT_GPIO_Port GPIOC
#define DROGUE_CONT_Pin GPIO_PIN_0
#define DROGUE_CONT_GPIO_Port GPIOB
#define MAIN_CONT_Pin GPIO_PIN_1
#define MAIN_CONT_GPIO_Port GPIOB
#define MAG_CS_Pin GPIO_PIN_12
#define MAG_CS_GPIO_Port GPIOB
#define MAG_INT_Pin GPIO_PIN_6
#define MAG_INT_GPIO_Port GPIOC
#define SD_DET_Pin GPIO_PIN_7
#define SD_DET_GPIO_Port GPIOC
#define DROGUE_H_Pin GPIO_PIN_8
#define DROGUE_H_GPIO_Port GPIOA
#define IO_RF_Pin GPIO_PIN_11
#define IO_RF_GPIO_Port GPIOA
#define GYRO_CS_Pin GPIO_PIN_12
#define GYRO_CS_GPIO_Port GPIOA
#define DROGUE_L_Pin GPIO_PIN_6
#define DROGUE_L_GPIO_Port GPIOB
#define GPS_PPS_Pin GPIO_PIN_7
#define GPS_PPS_GPIO_Port GPIOB
#define BARO_CS_Pin GPIO_PIN_8
#define BARO_CS_GPIO_Port GPIOB
#define ACCEL_CS_Pin GPIO_PIN_9
#define ACCEL_CS_GPIO_Port GPIOB

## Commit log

2022-09-22 Added features.xlsx
    [Features.xlsx]
2022-09-22 Added features.xls
    [915MHz_Radio.kicad_sch, Actuators.kicad_sch, Continuity_Testing.kicad_sch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]
2022-09-22 Added boost converter
    [Continuity_Testing.kicad_sch, Features.xlsx, Power.kicad_sch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]
2022-09-28 Added sensors
    [Actuators.kicad_sch, Data_Interfaces.kicad_sch, Data_Logging.kicad_sch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]
2022-09-29 Added BMX055
    [Actuators.kicad_sch, Continuity_Testing.kicad_sch, Power.kicad_sch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]
2022-10-04 Working SPICE sim for ematch continuity circuit
    [915MHz_Radio.kicad_sch, Actuators.kicad_sch, Continuity_Testing.kicad_sch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]
2022-10-23 Added power board, almost finished Strelka schematic
    [Actuators.kicad_sch, BMX055.kicad_sch, Data_Interfaces.kicad_sch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]
2022-10-24 Pin mapping and created STM32 .ioc for reference
    [BMX055.kicad_sch, Data_Interfaces.kicad_sch, L80-M39.kicad_sch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]
2022-10-24 Added to continuity circuit
    [Actuators.kicad_sch, Data_Interfaces.kicad_sch, Ematch.kicad_sch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]
2022-10-24 Added new UBLOX GPS
    [BMX055.kicad_sch, Data_Logging.kicad_sch, L80-M39.kicad_sch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]
2022-10-27 Added motor driver to power board
    [Actuators.kicad_sch, BMX055.kicad_sch, Buck_Converter.kicad_sch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]
2022-11-02 Switched order of pull-down resistor into ematch mostfet sw
    [Ematch.kicad_sch, Strelka_Flight_Computer.kicad_sch]
2022-11-02 Changed boost converter
    [Actuators.kicad_sch, Ematch.kicad_sch, L80-M39.kicad_sch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]
2022-11-02 Deleted extra boost circuit and L80 schematic
    [Power.kicad_sch, Sensors.kicad_sch, Strelka_Flight_Computer.kicad_sch]
2022-11-02 Started writing libraries for board functions
    [Strelka_Flight_Computer.kicad_pcb, Strelka_Flight_Computer.kicad_sch]
2022-11-06 Added working SPI comms test
2022-11-07 Started component placement
    [915MHz_Radio.kicad_sch, Actuators.kicad_sch, Ematch.kicad_sch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]
2022-11-09 First go at routing
    [Actuators.kicad_sch, Ematch.kicad_sch, Strelka_Flight_Computer.kicad_pcb]
2022-11-10 Power routing finished
    [Strelka_Flight_Computer.kicad_pcb]
2022-11-12 Creating BOM
    [915MHz_Radio.kicad_sch, Actuators.kicad_sch, Amass_XT30PW-M.stp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]
2022-11-12 redo placement
    [Data_Interfaces.kicad_sch, Data_Logging.kicad_sch, Ematch.kicad_sch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]
2022-11-13 PCB ordered
    [BMX055.kicad_sch, Data_Interfaces.kicad_sch, MS621FE-1.STEP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]
2022-11-13 Started ground station python
2022-11-19 Added firmware drivers - untested
    [Strelka_Flight_Computer.xlsx]

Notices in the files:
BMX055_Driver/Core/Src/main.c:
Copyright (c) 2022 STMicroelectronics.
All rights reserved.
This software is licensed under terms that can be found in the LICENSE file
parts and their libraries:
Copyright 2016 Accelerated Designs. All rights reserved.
